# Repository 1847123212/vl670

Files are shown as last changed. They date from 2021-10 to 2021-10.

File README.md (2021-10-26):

VL670/VL671 Development Board - USB 2.0 to 3.0 Transaction Translator
======================================================================

### Revision

This is version v0.02.

The original v0.01 design is obsolete, but it's still
[available here](https://notabug.org/niconiconi/vl670/src/v0.01).

### Introduction

#### The Problem

From a technical standpoint, USB 3.0 SuperSpeed (5 Gbps) is not an
upgrade to the existing USB 2.0 High-Speed (480 Mbps) standard,
instead, USB 3.0 is a completely new system of its own, which
operates independently from USB 2.0. Both the physical and protocol
layer have major differences. Backward compatibility is only maintained
by mandating all USB 3.0 devices to include a separate set of legacy
USB 2.0 controllers, transceivers, and wirings.

Because a USB 3.0 port is really a USB 3.0 and USB 2.0 port slapped
together, it creates some limitations.

* Bandwidth: You may want to simutaneously access multiple USB 2.0
devices, such as many USB flash drives, video cameras, or Software
Defined Radios (SDR) over a single USB 3.0 port using a USB hub,
since it has 5 Gbps bandwidth. However, you cannot do this - the total
bandwidth of all USB 2.0 devices is still limited to 480 Mbps, just
like a regular USB 2.0 port.

* Signal Extension and Isolation: Counter-intuitively, it's easier to
transmit USB 3.0 signals (not USB 2.0 High-Speed) over long distances,
or to galvanically isolate them. Its physical layer is actually simpler
than USB 2.0 - it uses two pairs of unidirectional, 8b/10b encoded,
differential signals. This type of signal is commonly found in almost
all high-speed digital systems, many standard hardware interfaces and
transceivers exist. On the other hand, USB 2.0 signaling is its own
design, its half-duplex nature further complicates the implementation.
Thus, in some non-standard custom systems, only a USB 3.0 link is
physically available.

For home and office users, both limitations may not be a problem,
but for hardware developers and experimenters who work with custom
systems, this can be problematic.

#### VL670/VL671 Transaction Translator

The VL670/671 is a specialized ASIC developed by VIA Labs, Inc., it's a USB
2.0 to USB 3.0 *transaction translator*, in other words, it translates the
legacy USB 2.0 traffic and transparently upgrades the device to an USB 3.0
SuperSpeed device by emulation, enabling a legacy USB 2.0 device to make use
of USB 3.0. By transparently upgrading a legacy USB 2.0 device to an emulated
USB 3.0 device, both problems are eliminated.

This is not a perfect solution, first, it's technically a violation of the
USB standards, also device compatibility is limited. Nevertheless, it's
still helpful to hardware developers and can solve many practical problems
in hardware Research and Development.

This technology is marketed as "SuperTT" (Super Transaction Translator)
by some OEM vendors.

#### My Project

Due to the specialized nature of the VL670/VL671 ASIC, it's almost unheard of
by most developers.

This project is an effort to create a free and open source hardware design of a
development board for the VL670/VL671 ASIC, to facilitate hardware evaluation and
experiments by other community developers, hopefully to help solving your USB
problems in your custom systems.

This development board is intended solely for hardware or software developers for
use in a research and development setting to facilitate evaluation, experimentation,
or technical analysis. It's not designed for consumer use, and it also should not be
used as a part or subassembly in any finished product.

#### Generations

VL670 is already obsolete. The second generation is VL671. This development board
supports both VL670 and VL671, and the use of VL671 is strongly recommended (though
not without its own problems).

Both chips are highly compatibile, the only modification needed is a single LED
output.  If VL670 is used, solder resistor `R9`, otherwise, solder resistor `R13`.

### Usage

#### LED Status

##### D2

* On: A USB 2.0 device has just connected and its traffic is being translated
to USB 3.0 traffic by VL67x (*VL670 only, not on VL671: or the processor is being
held in reset by the SPI header*).

* Off: A USB 3.0 or 2.0 device is connected and its traffic is passing
through VL670 as-is without any translation.

* Blink: Initial power-on reset, or a USB 2.0 device has just connected (*VL670
only, not on VL671*).

##### D20

* On: The power rail `+5V_SW` for downstream USB-A port is switched on.
Normally, this LED should be always on.

* Off: The power rail `+5V_SW` for downstream USB-A port is switched off.
This indicates the power supply circuit is malfunctional. First, check the
`5V` input, and whether the downstream USB port has a short circuit. Then,
check the USB power switch chip `U4` and pull-down resistor R15.

#### Voltage Level

All I/O are 3.3 V LVCMOS. Applying 5 V TTL level can damage the VL670,
its SPI flash, or both.

Before reading or writing to the Flash via SPI, the 5V power must also be
applied via the USB cable or the pin header. Attempting to program the SPI
Flash with an external programming without applying 5V power can damage
components.

#### SPI header

An SPI pin header is located at the top right of the board. By default, it's
connected directly to both the VL670 controller and its SPI Flash, allowing
one to probe the SPI bus while the controller is running. In this default mode,
applying voltages to the SPI header is prohibited, otherwise damage may occur.

To read or write the Flash via SPI, the `/EN` (a.k.a `ISP_ENABLE`) pin of the pin
header is grounded (by bridging pin 6 and 7 on the pin header), the processor is
cut off from the SPI bus and held in reset, giving the SPI pin header exclusive
access to the Flash.

For more information, see *Theory of Operation*, section *SPI Debugging and
Programming* and schematics.

#### GPIO header

All GPIO pin header is located at the top left of the board, exposing all
GPIOs of VL67x. Nevertheless, their functionality is unclear and it's
only useful for reverse engineering.

For more information, see *Theory of Operation*, section *Oddities* and
schematics.

### Known Issues

#### Limitations

1. If the USB-C cable is inserted very slowly, USB 3.0 fails, only USB 2.0
is detected, thus forcing the chip to enter USB 2.0 passthrough mode. This
is working by design and it's not a bug, however, it may cause misleading
or confusing behaviors, thus, `R1` and `R2` are removed by default, forcing
VL67x to always work in transaction translator mode.

2. In VL670, USB 3.0 passthrough is not reliable and it's not compatible
with some devices, this is a VL670 limitation. In VL671, USB 3.0 passthrough
is almost completely broken due to firmware limitation, the only compatible
device is a USB 3 Hub, direct attachment of a USB 3 device is not compatible.
Also, because the USB 3 signal path is doubled in passthrough mode, any cable
longer than 50 centimeters may cause enumeration failures. Thus, USB 3.0
passthrough mode should be avoided. If you want to test a combo USB 2/3 device,
I recommend using a pure USB 2.0 hub to completely isolate the USB 3 signals.

    * If you ever need to test USB 3.0 passthrough mode, you should always
    use a short USB-C cable, no longer than 50 centimeters to minimize signal
    loss. The ideal setup for USB 3 passthrough testing is: Host, 50 centimeter
    USB cable, VL671, very short USB cable, USB 3 Hub, device. Failure to follow
    it to cause enumeration and other failures. For USB 2 transaction mode, no
    special precaution is needed.

    * A hybrid VL670 w/ USB hub topology can be used to work around the
    problem, it's briefly in the next section of the document. USB redrivers
    and retimers can also solve the hardware problem (but not the firmware
    bug). Since USB 3 passthrough is already broken enough and adding either
    solution makes the project more complicated, I choose not to do it.

3. The upstream and downstream USB ports have no common-mode chokes for
the signals. Electromagnetic compatibility performance is limited. This
is an intentional decision, since adding them reduces the USB 3 link
budget needed for the already problematic USB 3 passthrough mode.

4. Not all devices are supported by the transaction translator. Sometimes
the incompatibility is a hardware or protocol limitation, other times it
can be a driver problem - many drivers make certain assumptions of the USB
device, which may no longer be true after the device is emulated by VL670
as a SuperSpeed device.

    * USB Attached SCSI (UAS) doesn't work in transaction translator mode.
    But it can be disabled at the device driver of the operating system.

### Images

#### Front and Back of the PCB

Front and Back of the PCB

### Schematics

* [PDF schematics](https://notabug.org/niconiconi/vl670/raw/main/schematics/vl670-schematics.pdf)

* [PDF layout](https://notabug.org/niconiconi/vl670/raw/main/schematics/vl670-layout.pdf)

### BOM

* [Bill of Material](https://notabug.org/niconiconi/vl670/src/main/bom)

### Datasheets

Datasheets for all components on the development board can be found at GitLab.

* [Datasheets Repository](https://gitlab.com/niconicon1/vl670-datasheets)

It contains the following documents.

* [VL670 USB2.0 to USB3.0 Transaction Translator](https://gitlab.com/niconicon1/vl670-datasheets/-/raw/main/DS_VL670_115.pdf)

* [VL671 Low Power USB 2.0 to USB 3.1 Gen1 Transaction Translator](https://gitlab.com/niconicon1/vl670-datasheets/-/raw/main/DS_VL671_080.PDF)

* [HD3SS3220 USB Type-C DRP Port Controller with SuperSpeed 2:1 MUX](https://gitlab.com/niconicon1/vl670-datasheets/-/raw/main/hd3ss3220.pdf)

* [TPS20xxC and TPS20xxC-2 Current Limited, Power-Distribution Switches](https://gitlab.com/niconicon1/vl670-datasheets/-/raw/main/tps2061c.pdf)

* [GD25D10C/05C 3.3V Uniform Sector Standard and Dual Serial Flash](https://gitlab.com/niconicon1/vl670-datasheets/-/raw/main/GD25D05C.pdf)

* [SN74LVC2G66 Dual Bilateral Analog Switch](https://gitlab.com/niconicon1/vl670-datasheets/-/raw/main/sn74lvc2g66.pdf)

* [ESD7104 Low Capacitance ESD Protection Diode for High Speed Data Line](https://gitlab.com/niconicon1/vl670-datasheets/-/raw/main/ESD7104-D.PDF)

* [ESD5B5.0ST1G-N ESD Protection Diode](https://gitlab.com/niconicon1/vl670-datasheets/-/raw/main/ESD5B5.0ST1G-N.pdf)

### Firmware

The firmware for the SPI Flash can be found at GitLab. Both VL670 and VL671
firmware files are included.

* [SPI Flash Firmware](https://gitlab.com/niconicon1/vl670-firmware)

#### Non-Free

Unfortunately, VL670/671 is driven by a microcontroller and requires a
proprietary firmware to operate.

Nevertheless, the firmware is burned into the Flash memory only once after
the device is assembled, and it's fetched by the VL670 ASIC itself, not
uploaded from a user's host computer, nor it executes any code on a user's
host computer or operating system. If we make the firmware read-only and
unmodifiable by pure software, the firmware effectively "vanishes" from the
software domain and becomes a part of the hardware itself, making the hardware
qualifies as free device, just like [how OpenMoko did it](https://lwn.net/Articles/460654/).
Another benefit is improved security, as malicious software is unable to
reprogram the firmware via USB to launch a BadUSB attack.

This is implemented as jumper `JP1`, once the jumper is hardwired on the board,
the Flash is read-only and cannot be modified by software without hardware
modifications.

That being said, this is a somewhat "underhanded" way to bypass the free software
and hardware requirements and this behavior stays exactly at the borderline of
the definition of "free", just moving one more nanometer away makes it non-free.
This is hardly satisfactory! But this is all we have at the current moment.

#### Reverse Engineering

The long term solution is reverse engineering the firmware and writing a free and
open reimplementation. This also enables us to customize the firmware for our
needs, fixing bugs in the firmware, and understanding the behavior of the hardware
better.

But before you start, note that VL670 is already obsolete, its internal
microcontroller also uses an unknown custom architecture, I suspect it's
Xtensa. Its replacement, VL671, uses a different microcontroller (ARM Cortex M3)
and a different firmware.

I suggest leaving the proprietary VL670 firmware as-is since its architecture
is less known and the chip is already obsolete. Instead, work on the VL671
firmware instead.

### Theory of Operation

#### Overview

The heart of the development board is the VL67x controller (`U2`). It has two USB
interfaces on both sides of the chip. The left side is the host side, connnected
to a computer via a USB 3.0 Type-C port (`J2`), the right side is connected to
the device side, via a USB 3.0 Type-A port. All the transaction translation
magic is performed internally by VL67x.

When a USB Type-C cable is plugged into the development board, 5 V power is
applied to the board by the host, the decoupling capacitors on the 5 V rail
starts charging up. Shortly after the 5 V rail settles, the internal power
converters inside the VL67x controller (`U2`) are activated. They are a 3.3 V
LDO, a 1.5 V DC/DC, and a 1.2 V LDO converter, generating the three power rails
for VL670 (on VL671, the 1.5 V & 1.2 V is merged into a single 1.2 V DC/DC
converter), the SPI Flash (`U6`), and the SPI multiplexers (`U3` and `U5`).

When 3.3 V is ready, the VL67x controller (`U2`) leaves the power-on reset
state, timed by the RC circuit `R4` and `C13`, and the processor core inside
VL67x starts operating. VL67x fetches firmware code from the Flash chip GD25D05
(`U6`) via the SPI bus.

Meanwhile, back to USB (`J2`), at the host side, the incoming 3.0 signal lines from
the Type-C cable is demultiplexed by the USB Type-C controller HD3SS3220 (`U1`)
by selecting the correct signal pairs based on the orientation of the Type-C
plug. It occurs almost as soon as the USB cable is plugged in. On the other hand,
the USB 2 signals are shorted together and don't require active demultiplexing.
At this point, VL67x gains access to both USB 3.0 and USB 2.0 signals at the
host side.

Strictly speaking, only the USB 3.0 signals are required since VL67x is a
transaction translator that converts all USB 2.0 traffic to USB 3.0 transparently.
The USB 2.0 differential pair at the host side is only for compatibility -
if one plugs the board into a USB 2.0 port, VL67x disables transaction and enters
USB 2.0 passthrough mode. Because this fallback behavior can confuse the developer
(e.g. for example, if the USB 3.0 cable is defective and the chip always enters
USB 2.0 passthrough mode), optional jumpers, `R1` and `R2`, are installed on the
the USB 2.0 signal lines. USB 2.0 is disconnected completely when the resistors
are removed to simulate a nonstandard, pure USB 3.0 host port without USB 2.0
connection.

Once the firmware in VL67x decides that it's ready, `/DN_PWREN` (pin 37) outputs
a logical `0`, enabling power switch TPS2061C (`U4`) to provide 5 V power (called
`+5V_SW`, for "switched 5 V") to the downstream, device-side USB port (`J4`).
TPS2061C also provides soft-start and short-circuit protection. At this point,
VL67x is ready to accept a USB device.

At the device side, `DN_D-`, `DN_D+`, `DN_USB3RX-`, `DN_USB3RX+`, `DN_USB3TX-`,
`DN_USB3TX+` are connected to a USB Type-A port.

When a USB device is plugged in to the USB-A connector (`J4`)...

* If it's a USB 2.0 device and if USB 3.0 is available at the host side, the
USB 2.0 traffic is translated to USB 3.0 traffic by VL67x. The host should
detect a USB 3.0 SuperSpeed device. The translation is transparent, VL67x
itself is invisible to the host, only the device is.

* If only USB 2.0 is available at the host, VL67x enters USB 2.0 passthrough
mode for all USB 2.0 or USB 3.0 devices, without translation. The host should
detect a USB 2.0 device. This mode is also entered if the USB 3.0 at the host
side has failed. A defective cable is a common cause, but inserting the USB
Type-C cable extremely slowly has the same effect. Removing `R1` and `R2` to
disable USB 2.0 at the host completely can avoid this confusing situation.

* If both the host and device support USB 3.0, VL67x enters passthrough mode
without translation.

#### USB Type-C and HD3SS3220

For developer's convenience, the USB host side uses a USB 3.0 Type-C connector
instead of a bulky and uncommon USB 3.0 Type-B or Micro-USB connector.

A USB 3.0 Type-C connector is reversible, thus it has two possible connections:
either `D1+`, `D1-`, `TX1+`, `TX1-`, `RX1+`, `RX1-` are connected, or `D2+`, `D2-`,
`TX2+`, `TX2-`, `RX2+`, `RX2-` are connected. USB 2.0 operates at a slower
frequency, thus `D1+/-` and `D2+/-` pairs are simply shorted together, allowing
a connection regardless of the plug orientation.

On the other hand, this is unacceptable for USB 3.0 - the extra length of an
open-ended wiring creates a quarter-wave stub, which is detrimental to signal
integrity. Instead of passively connecting them together, an active electronic
switch, known as an demultiplexer, should be used to select one out of two
pairs.

The solution is HD3SS3220 (`U1`), it's a USB-C controller with built-in
switches. It automatically selects the correct differential pair, either `TX1+`,
`TX1-`, `RX1+`, `RX1-` or `TX2+`, `TX2-`, `RX2+`, `RX2-`, based on the
orientation of the Type-C plug as soon as a Type-C cable is plugged in.
The demultiplexed signal is simply called `TX+`, `TX-`, `RX+`, `RX-`,
just like the signal coming out from a traditional USB 3.0 Type-B connector.

##### DC Biasing

The `TX-` and `TX+` pins on the HD3SS3220 can only tolerate a common-mode
DC voltage below 2 V. But VL67x's common-mode DC voltage at SSTX is 2.2 V. Two
extra capacitors, C5 and C6 are needed in this particular design to prevent
VL67x's DC bias from reaching HD3SS3220.

Simultaneously, HD3SS3220 won't work without a DC bias at the `TX-` and `TX+`
pins. Thus, R16 and R17 are needed to reestablish a DC operating point. 0 V
is acceptable, thus both are pulled down to GND. The resistors are unnecessary
without HD3SS3220.

#### SPI Debugging and Programming

An SPI pin header (`J3`) is provided at the top right of the board. The header is
directly connected to the signal lines between the VL67x controller and the
GD25D05 (`U6`) SPI Flash, allowing one to attach a logic analyzer to monitor the
bus while the controller is running.

To allow a developer to read or write the Flash via SPI directly without a
potentially destructive bus contention, VL67x's SPI bus is gated by two
74LVC2G66 CMOS analog switches (`U3` and `U5`). When the `/EN` (a.k.a `ISP_ENABLE`)
pin of the pin header is grounded (by bridging pin 6 and 7 on the pin header),
the processor is cut off from the SPI bus, giving the SPI pin header exclusive
access to the Flash. The `/EN` signal is also directly connected to the `/RESET`
signal of VL67x to halt the processor.

#### External Power

A power pin header (`J5`) is provided. However, it should never be used to power
the development board when the USB Type-C port is plugged in, otherwise a short
circuit may occur. If debugging the board with external power is desirable, cut
the trace at PCB jumper `JP2` with a knife.

The jumper is located at the back side of the board. There are two jumpers, so
make sure you're cutting `JP2`. Use a multimeter to confirm the connection is
truly broken.

Once `JP2` is cut, the USB Type-C port no longer provides power to the
development board. Signals and ground connections remain.

#### Oddities

Due to OEM firmware differences, some pins do different things than what
they were intended to do. These differences were obtained via hardware
reverse engineering.

##### GPIO

* `GPIO1_3 / DN_PWREN` is meant to be an `/ENABLE` signal to the downstream
USB port, but it seems to be high-impedance and unused by the firmware. Thus,
the USB power switch U2 is optional and can be removed. Its only purpose is
short circuit protection.

##### USB 3 Passthrough

The reverse-engineered hardware uses a slightly different topology -
VL67x is attached to an upstream USB 3.0 hub as a subdevice, and only
USB 2.0 signals are wired to the downstream VL670, the USB 3.0 signals
are directly wired to the upstream hub. This can be understood as an
attempt to improve compatibility. In my tests, I found the USB 3.0
passthrough offered by VL670 is not always reliable and some devices
cannot be used, and on VL671 it's essentially broken due to firmware
limitations. Furthur, because the USB 3 signal path is doubled in
passthrough mode, it completely breaks the USB link budget, any cable
longer than 50 centimeters may cause enumeration failures.

Thus, passthrough mode should be avoided. Wiring the USB 3.0 signal
directly to the host via a USB 3.0 hub is beneficial.

For simplicity, this is not implemented on this development board. But
it's necessary for a finished product.

##### VL670 GPIO

* `GPIO1_2 / GPIO_TP3` is officially unused, but the OEM firmware uses it as
an input for deciding whether to enable VL670. On this development board, this
pin is pulled down by a resistor, otherwise the USB connection would reset
randomly.

On the reverse-engineered hardware, the downstream hub `/ENABLE` seems to
be Wired-Or together with `DN_PWREN` output, the `ENABLE` pin output from
the upstream USB Hub (to allow both chips to make a `ENABLE` decision?),
and the input `GPIO1_2`. It appears to be a workaround to allow the use
of aforementioned hybrid topology.

* `GPIO1_0 / GPIO_TP1` is officially unused, but the OEM hardware connects it
to the USB hub's (not VL670's own) private SPI bus, between the hub and its SPI
firmware Flash, monitoring the `MISO` signal. On this development board, this
pin is pulled down by a resistor. Although it seems to work without one, but
leaving the input in a known state is still desirable as we don't really
understand its purpose.

Again, a odd design, and I suspect the firmware is using it as an interrupt
signal to detect whether the USB hub is active for logic sequencing or
synchronization in this hybrid VL670 w/ hub topology.

* `GPIO3_0 / STATUS` is meant to be the LED indicator output, but the
firmware uses `GPIO1_1/GPIO_TP2` instead.

* `UART_RX` and `UART_TX` - no traffic observed. More hacking required.

#### Power Distribution Network

##### Overview

The Power Distribution Network is decoupled using the standard method of
"one capacitor per pin, all capacitors have the same value."

The 1.5 V rail and 1.2 V rail are decoupled using 1 uF capacitors, all
0603-sized, nothing unusual (but do note C44 is the output capacitor of
the DC/DC converter).

The 3.3 V rail uses multiple (20+) 470 nF capacitors and deserves more
attention: C31-C35 are meant for power supply decoupling, and are 0603-sized.
C71-C82 however, serve double duties, they are placed near vias to provide a
continuous AC return path for signals travelling between layers ("plane
stitching"), thus are 0402-sized to fit in the tight space near vias. Due to
the higher number of capacitors for plane stitching, smaller 470 nF capacitors
are used to keep the total capacitance per rail under 10 uF to prevent inrush
current.

##### USB Inrush Current

The 5 V rail requires special care, it's directly attached to the USB power
input, thus will produce a huge inrush current, which should stay within the
USB spec limits. Basically, the rules of the USB spec is:

1. Inrush current less than 100 mA is always acceptable, it's only considered
as an inrush event when 100 mA is exceeded.

2. If an inrush event occurs, the maximal *charge* transfered, calculating by
area under the current curve, should be less than 50 uC. For 5 V, it means the
equivalent capacitance should be less than 10 uF. Only *charge* is limited, not
inrush current itself, because the goal is to avoid draining the output
capacitance at the upstream by too much, the absolute current is irrelevant (of
course, unless it's low enough to apply rule No.1).

3. If two inrush events are separated by 100+ us, they are considered as two
separate events. Only the "biggest" inrush event is considered, all other
events are ignored. Thus, it's possible to get more capacitance allowance
by delayed startup.

Measurements showed that the only significant inrush current of this development
board is caused by capacitors at 5 V rail, other power rails produces almost no
inrush current, presumably, the LDO and DC/DC's startup is "soft" enough.
Moreover, the current capacitance on 5 V rail is rather conservative, only 5 uF,
due to the delayed (100 us+) startup of `+5V_SW` rail, the total capacitance
allowed on the +5 V rail is effectively doubled, up to 20 uF (effectively 10 uF
due to ceramic capacitance loss under DC bias, giving us some extra headroom).

##### Ferrite Resonance and Damping

A ferrite choke, FB1, is used in series of the 5 V input at the USB port to
filter high-frequency noise. However, its series inductance, when combined
with parallel capacitance, forms a parallel LC circuit on the 5V rail. This
creates a huge impedance spike at the resonance frequency. If this frequency
is excited by noise, it create a huge noise voltage. To reduce its impact,
two small 0.5-ohm resistors are connected in series with the ceramic capacitors,
C19 and C20.

##### Capacitor Value Selection

Finally, it should be noted that a 0.1 uF capacitor is traditionally seen as
a "high-frequency capacitor" and is the prefered choice for power decoupling,
and is often blindly combined with 1 uF capacitors to "cover both high and
low frequencies." However, many recent books by domain experts have pointed out
that this practice is counterproductive. First, blindly mixing capacitor
values can create anti-resonance impedance peaks and actually make the
decoupling worse at some frequencies. Second, considering that this rule of
thumb originated from the through-hole era, meanwhile the parasitic inductance
of modern SMD ceramic capacitors is so low, they all have fairly good
high-frequency performance regardless of their values, their effectiveness is
mainly limited by package size and PCB inductance. Thus, the modern, updated
guideline is to use the same capacitance everythere. That being said, there
are still important uses and benefits for mixing different capacitance, but
only if careful calculation and simulation is performed to predict and control
the anti-resonance peaks - which is overkill for this board.

For the argument against multiple capacitor values, see *Electromagnetic
Compatibility Engineering* by Henry Ott, Chapter 11 *Digital Circuit Power
Distribution*, Section 11.4.1 *Multiple Decoupling Capacitors*. And for the
argument for multiple capacitor values, but with careful design and simulation,
see *Principles of Power Integrity for PDN Design* by Larry D. Smith and Eric
Bogatin, Chapter 8 *The PDN Ecology*, Section 8.17 *Using Three Different
Values of MLCC Capacitors on the Board*.

P.S: Smith & Bogatin's conclusions are terrifying, I'll just pretend that I
don't know that...

#### PCB Stack-up

This is a 4-layer PCB, using the Signal-Ground-Power-Signal stack-up
with impedance controlled traces, and fabricated by JLCPCB's JLC2313
stack-up. The dielectric constant of the board is 4.05, the distance
between the signal and its reference plane is 0.1 mm.

JLC2313 is selected for its closer distance between the signal and its
reference plane in comparison to JLC7628, which allows thinner traces
and reduced crosstalk.

### License

Copyright (C) 2021 Tom Li (niconiconi)
"No Rights Reserved"

This is a free hardware design: to the extent possible under law, the designer
has waived all copyright and related or neighboring rights, you can reuse,
modify, redistribute this design, as freely as possible in any form whatsoever
and for any purposes, including commercial purposes, under the terms of the
*CC0 1.0 Universal License*.

This hardware design is offered as-is and the designer makes no representations
or warranties of any kind concerning the design, express, implied, statutory or
otherwise, including without limitation warranties of title, merchantability,
fitness for a particular purpose, non infringement, or the absence of latent
or other defects, accuracy, or the present or absence of errors, whether or
not discoverable, all to the greatest extent permissible under applicable law.

See the *CC0 1.0 Universal License* for more details.

You should have received a copy of the *CC0 1.0 Universal License* along with
this hardware design. If not, see https://creativecommons.org/publicdomain/zero/1.0/legalcode

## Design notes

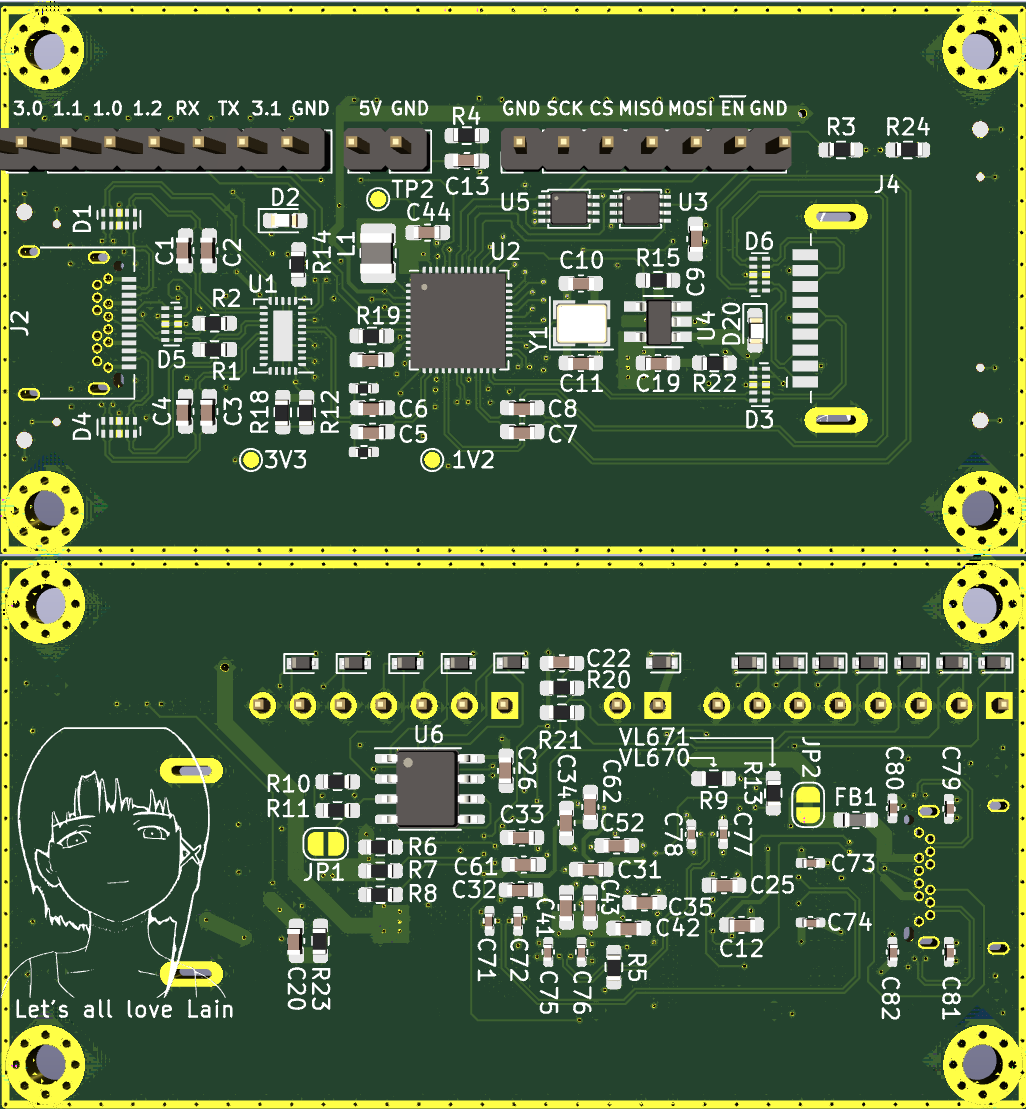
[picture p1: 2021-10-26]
photos/pcb_render.png

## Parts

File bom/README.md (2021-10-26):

VL670 Development Board - BOM
===============================

Don't trust the price data too much. 

### PCB

| Component |  Quantity  | Price  | Total Low Qty. Price
| --- | --- | --- | --- |
| JLCPCB, 4-layer, JLC2313 stack-up, ENIG | 1 | 4.72  | 23.58 |
| | | =  4.72  | = 23.58 |

### Assembly
| Component |  Quantity  | Price  | Total Low Qty. Price
| --- | --- | --- | --- |
| JLCPCB, stencil, etch-polishing | 1 | 0.000  | 14.48 |
| | | = 0.000  | = 14.48 |

### Capacitors

| Component |  Quantity | Price  | Total Price | Total Low Qty. Price 
| --- | --- | --- | ---| --- |
| 0603 X7R 220nF | 8 | 0.0115 | 0.092 | 0.575 |
| 0603 NP0  18pF | 2 | 0.0051 | 0.0102 | 0.255 |
| 0603 X7R 1uF | 10 | 0.0254 | 0.3048 | 0.508 |
| 0603 X7R  10uF | 2 | TBD  | TBD | TBD |
| 0603 X7R 470nF | 9 | 0.0198 | 0.1782 | 0.99 |
| 0402 X7R 470nF | 12 | 0.0124 | 0.1488 | 0.62 |
| | | |  = 0.7344 | = 3.618 |

### Resistors

| Component |  Quantity | Price  | Total Price | Total Low Qty. Price
| --- | --- | --- | ---| --- |
| 0603 5%  0.5  | 2 |  TBD | TBD | TBD |
| 0603 5% 10K | 7 | 0.0046 | 0.0322  | 0.23 |
| 0603 5%  470  | 1 | 0.0013 | 0.0013  | 0.13 |
| 0603 1% 11.3K | 1 | 0.0014 | 0.0014  | 0.14 |
| 0603 1%  1.8M | 2 | 0.0016 | 0.0032  | 0.16 |
| 0603 5%  200K | 1 | 0.0459 | 0.0459  | 0.46 |
| 0603 -% 0  | 6 | 0.0015 | 0.0090  | 0.15 |
| 0402 5%  100K | 2 | 0.0117 | 0.0234  | 0.59 |
| | | | = 0.4062  | = 1.86 |

### Inductors & Ferrites

| Component | Value |  Vendor |  Quantity  | Price  | Total Price | Total Low Qty. Price
| --- | ---  | --- | --- | --- | --- | --- |
| SPH252012H4R7MT | 0603 4.7uF |  Sunlord | 1 |  0.1178  | 0.1178 | 1.18 |
| BLM18KG221SN1D  | 0606 220R/2.2A |  Murata | 1 | TBD | TBD | TBD |
| | | | | | = 0.1178 | = 1.18 |

### ESD Suppression Diodes

| Component | Vendor |  Quantity |  Price  | Total Price | Total Low Qty. Price
| --- | ---  | --- | --- | --- | --- |
| UDFN  ESD7104 | OnSemi | 5 |  0.0987 | 0.4935 | 1.2326 (shortage!) |
| SOD-523 ESD5B5.0ST1G-N | Born Semiconductor | 12 |  0.0368 | 0.4416 | 0.74 |
| | | | | = 0.9351 | = 1.9726 |

### Connectors

|  Component | Value |  Vendor |  Quantity  |  Price  | Total Price | Total Low Qty. Price
| --- | --- | --- | --- | --- | --- | --- |
|  USB 3 Type-C  | U262-241N-4BV60 | XKB | 1 |  0.5266 | 0.5266 | 0.53 |
|  USB 3 Type-A  | U231-091N-4BLRA00-S-1 | XKB | 1 |  0.1722 | 0.1722 | 0.1722 |
| 2.54mm header  | 01x02, 01x07 | - | 1 |  0.0244 | 0.0244 | 0.0244 |
| | | | | |  = 0.7232 | = 0.7266 |

### Misc

| Component | Value |  Vendor |  Quantity  |  Price  | Total Price | Total Low Qty. Price
| --- | --- | --- | --- | --- | --- | --- |
| 0603 Blue  LED  | Blue | - | 1 | 0.0294  | 0.0294 | 0.59 |
| 3225 25MHZ XTAL |  25 MHz, Cl=10pF  | - | 1 | 0.0098  | 0.0098 | 0.49 |
| | | | | |  = 0.0392 | = 1.08 |

### ICs

| Component | Vendor |  Quantity | Price  | Total Price | Total Low Qty. Price
| --- | ---  | --- | --- | --- | --- |
|  QFN-48 VL67X |  VIA Labs | 1 |  3.0817  | 3.0817 | 4.6225 |
| WQFN-30 HD3SS3220 | TI | 1 |  1.7907  | 1.7907 | 3.4515 (shortage!) |
| VSSOP-8 74LVC2G66 |  Nexperia, TI | 2 |  0.2337  | 0.4674 | 0.4674 |
|  SOIC-8 GD25D05 |  GigaDevice | 1 |  0.4097  | 0.4097 | 2.00 |
| SOT-23-5 TPS2061C-PXLI | TI | 1 |  0.7682  | 0.7682 | 0.7682 |
| | | | | = 6.5177 | = 11.3096 |

### Total:

| Component |  Total Price  | Total Low Qty. Price
| --- | --- | --- |
| PCB | 4.72 | 23.58 |
| Capacitors | 0.7344 | 3.618 |
| Resistors | 0.4062 | 1.86 |
| Inductors | 0.1178 | 1.18 |
| ESD Suppression Diodes | 0.9351 | 1.9726 |
| Connectors | 0.7232 | 0.7266 |
| Misc | 0.0392 | 1.08 |
| ICs | 6.5177 | 11.3096 |
| |  = 14.196 | = 46.50 |
| + assembly | | = 60.99 |

Note: the "Total Low Qty. Price" is only for my personal reference, the method
is not rigorous and seems to overestimates the sample board cost. The "true"
cost is probably $20.

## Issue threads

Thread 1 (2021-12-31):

Supertt adapter v2

docop, 2021-12-31:
Hi So this is a very great project. I spend lot of time to find out those unit and overall only 1 place in china did do it. But it do heat up to the point to burn. quite special.  Is yours, based on the ref design get any heat issues ?
 And did you have working prototype of your v2 version ? or made multiple..
thanks in advance

docop, 2023-03-16:
Also, is the hid usb1 do transfert too ?

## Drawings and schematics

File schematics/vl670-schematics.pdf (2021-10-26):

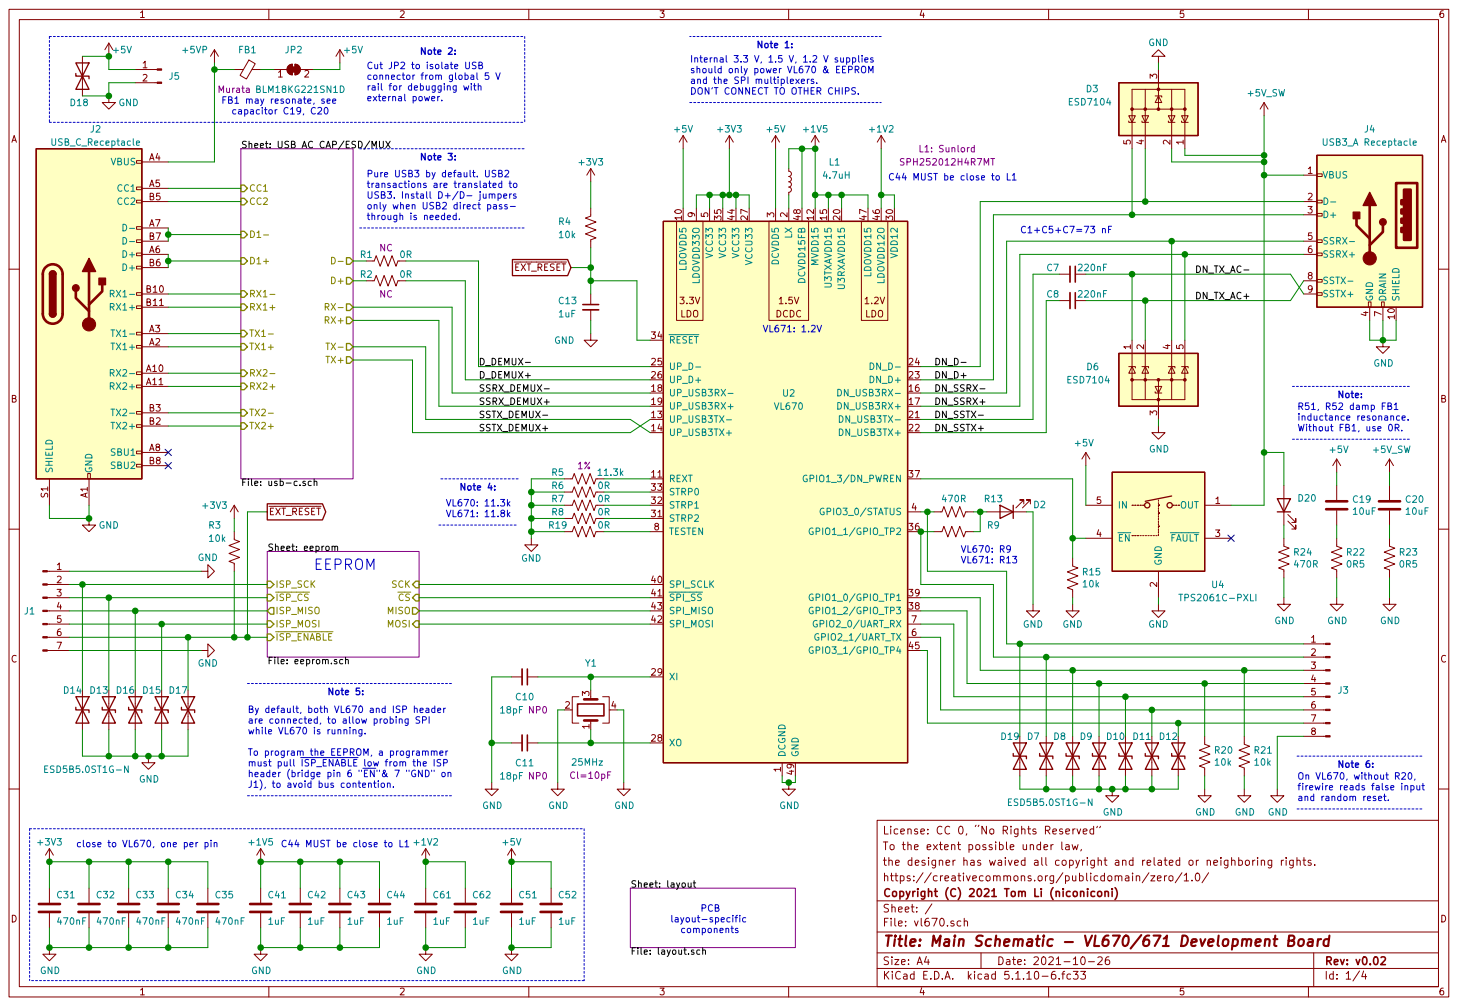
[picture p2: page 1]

and the SPI multiplexers. DON'T CONNECT TO OTHER CHIPS. VL670: 11.3k VL671: 11.8k Cut JP2 to isolate USB
connector from global 5 V
rail for debugging with
external power.

Internal 3.3 V, 1.5 V, 1.2 V supplies
should only power VL670 & EEPROM

Sheet: USB AC CAP/ESD/MUX

inductance resonance. Without FB1, use 0R. Note 3: Pure USB3 by default. USB2

SPH252012H4R7MT
C44 MUST be close to L1

transactions are translated to USB3. Install D+/D- jumpers

only when USB2 direct pass-

By default, both VL670 and ISP header
are connected, to allow probing SPI
while VL670 is running.

To program the EEPROM, a programmer
must pull ISP_ENABLE low from the ISP
header (bridge pin 6 "EN"& 7 "GND" on

firewire reads false input and random reset. Note 6:
On VL670, without R20,

License: CC 0, No Rights Reserved
To the extent possible under law,
the designer has waived all copyright and related or neighboring rights.
https://creativecommons.org/publicdomain/zero/1.0/
File: vl670.sch Sheet: / Copyright (C) 2021 Tom Li (niconiconi)

Id: 1/4 Title: Main Schematic - VL670/671 Development Board

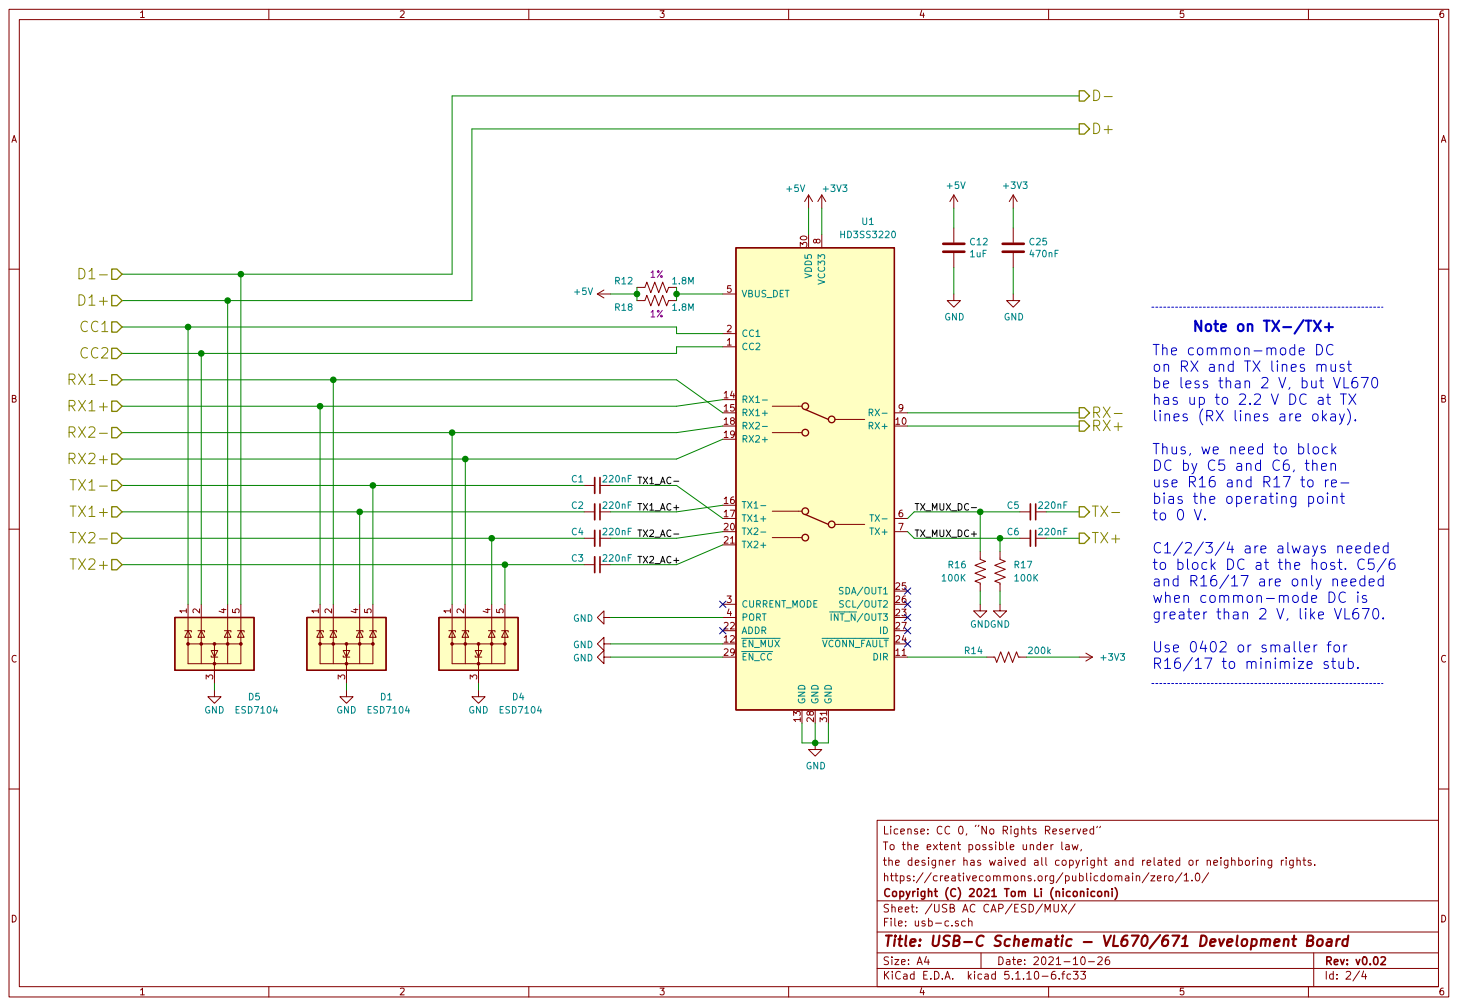
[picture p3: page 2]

The common-mode DC
on RX and TX lines must
be less than 2 V, but VL670
has up to 2.2 V DC at TX
lines (RX lines are okay).
Thus, we need to block
DC by C5 and C6, then
use R16 and R17 to re-
bias the operating point
C1/2/3/4 are always needed
to block DC at the host. C5/6
and R16/17 are only needed
when common-mode DC is
greater than 2 V, like VL670.
Use 0402 or smaller for
R16/17 to minimize stub.

License: CC 0, No Rights Reserved GND

To the extent possible under law,
the designer has waived all copyright and related or neighboring rights.
https://creativecommons.org/publicdomain/zero/1.0/
File: usb-c.sch Sheet: /USB AC CAP/ESD/MUX/ Copyright (C) 2021 Tom Li (niconiconi)

Id: 2/4 Title: USB-C Schematic - VL670/671 Development Board

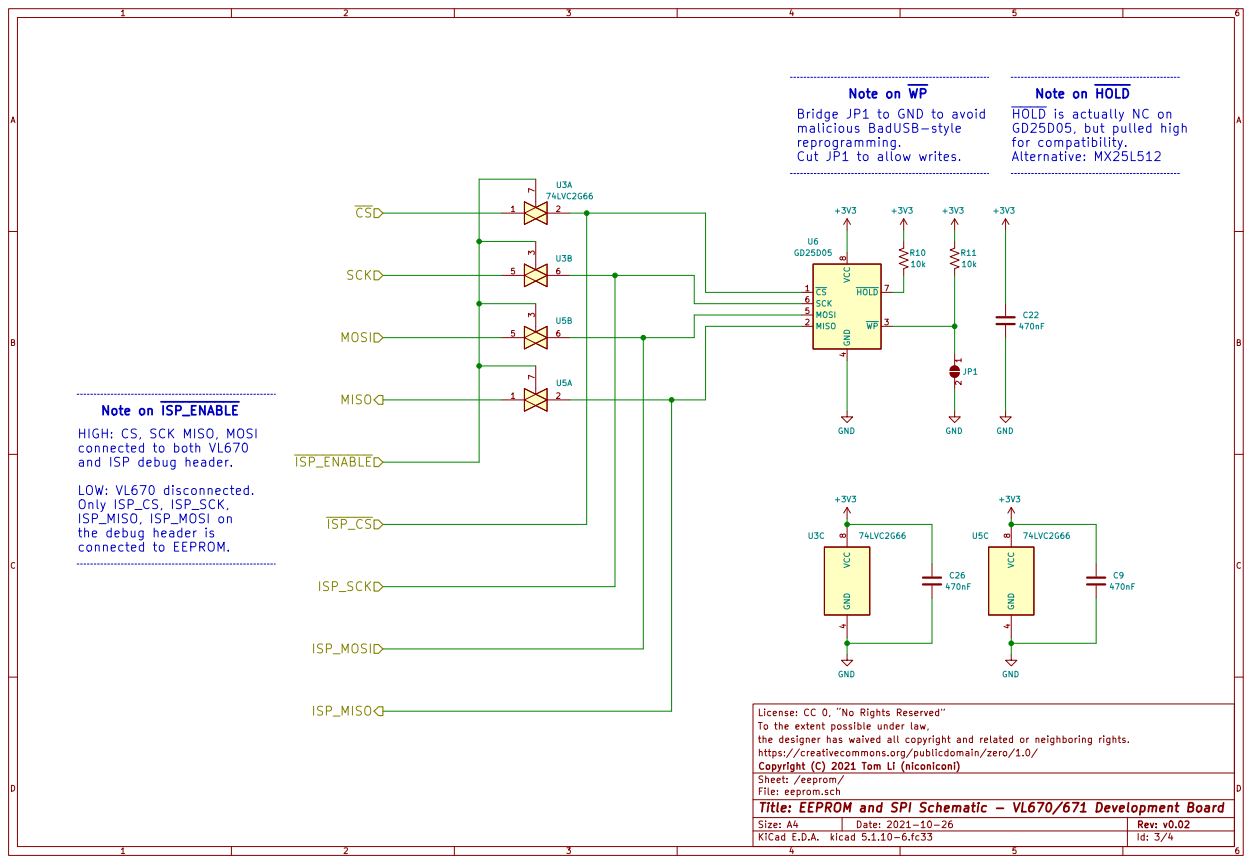
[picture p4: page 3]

Bridge JP1 to GND to avoid
malicious BadUSB-style
reprogramming.
Cut JP1 to allow writes.

HOLD is actually NC on
GD25D05, but pulled high
for compatibility.
Alternative: MX25L512

4 MOSI 5 SCK 6 HOLD 7 VCC

Note on ISP_ENABLE
HIGH: CS, SCK MISO, MOSI
connected to both VL670
and ISP debug header.
LOW: VL670 disconnected.
Only ISP_CS, ISP_SCK,
ISP_MISO, ISP_MOSI on
the debug header is
connected to EEPROM.

License: CC 0, No Rights Reserved GND

To the extent possible under law,
the designer has waived all copyright and related or neighboring rights.
https://creativecommons.org/publicdomain/zero/1.0/
Copyright (C) 2021 Tom Li (niconiconi)
Sheet: /eeprom/
File: eeprom.sch
Id: 3/4 Title: EEPROM and SPI Schematic - VL670/671 Development Board

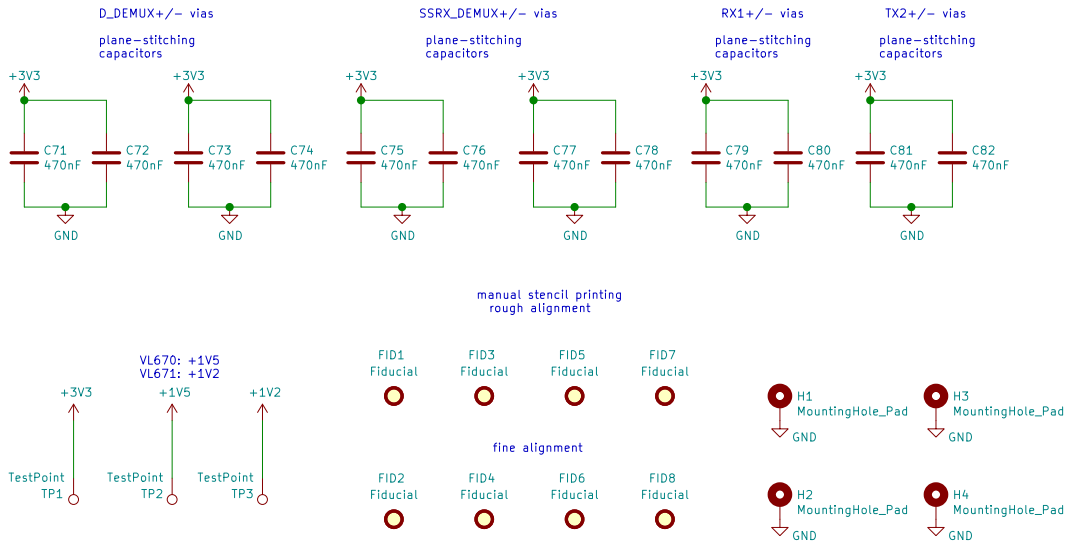
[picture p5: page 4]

fine alignment D_DEMUX+/- vias plane-stitching

License: CC 0, No Rights Reserved
To the extent possible under law,
the designer has waived all copyright and related or neighboring rights.
https://creativecommons.org/publicdomain/zero/1.0/
Copyright (C) 2021 Tom Li (niconiconi)
Sheet: /layout/
File: layout.sch
Id: 4/4 Title: PCB-specific Schematic - VL670/671 Development Board

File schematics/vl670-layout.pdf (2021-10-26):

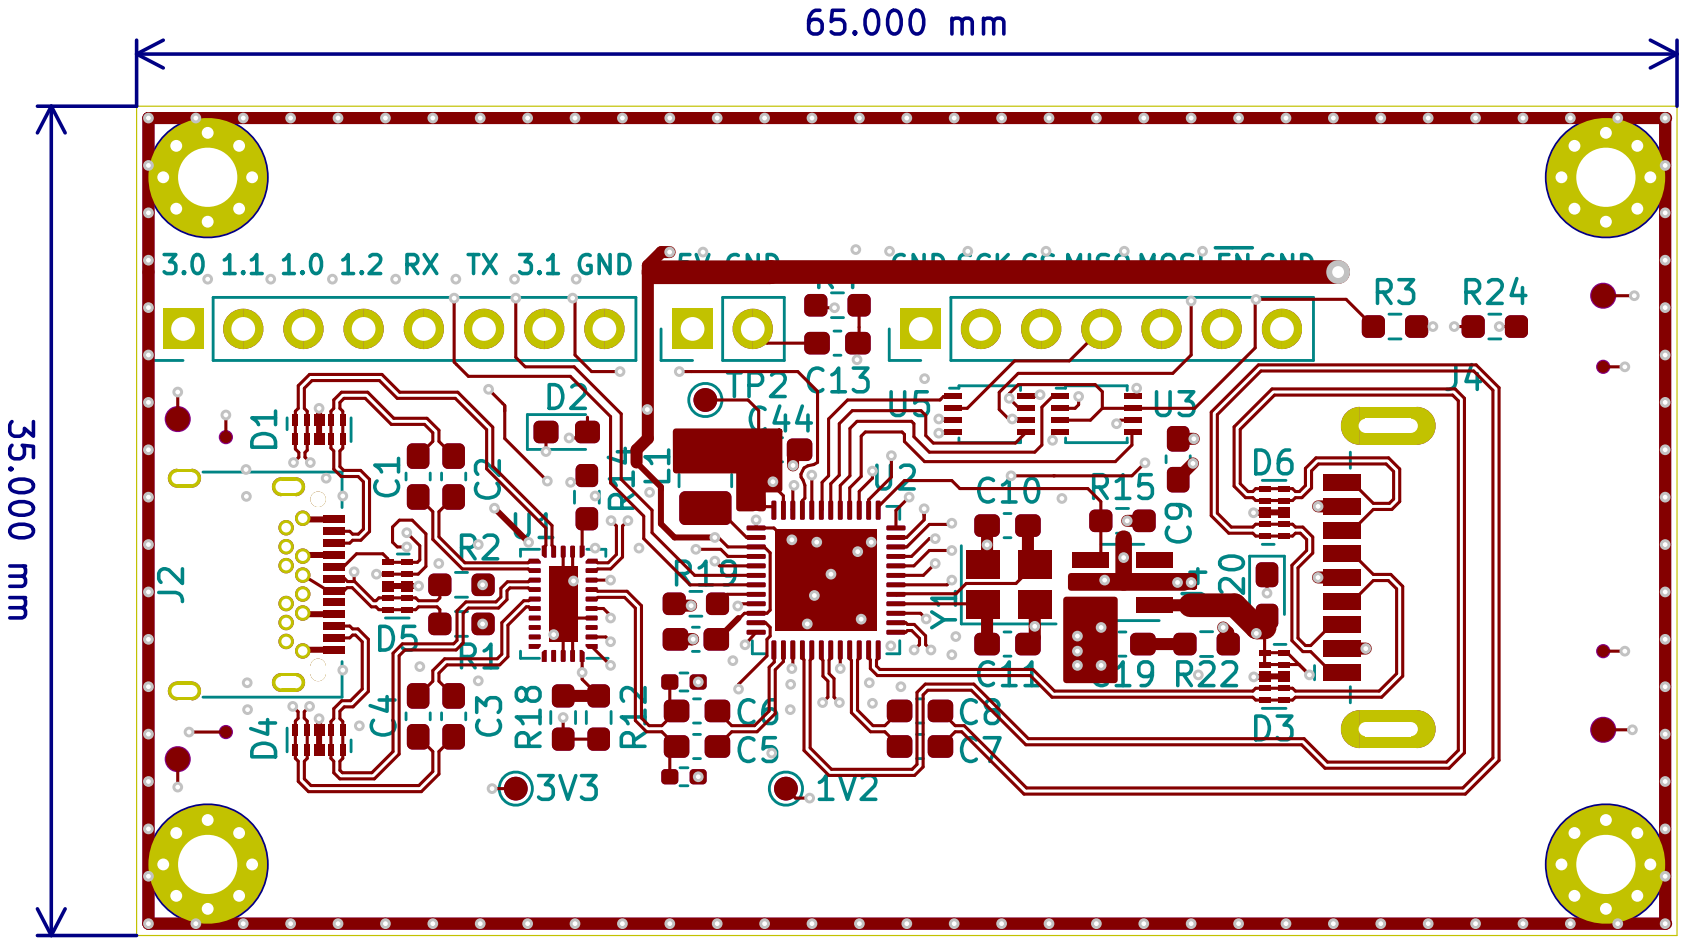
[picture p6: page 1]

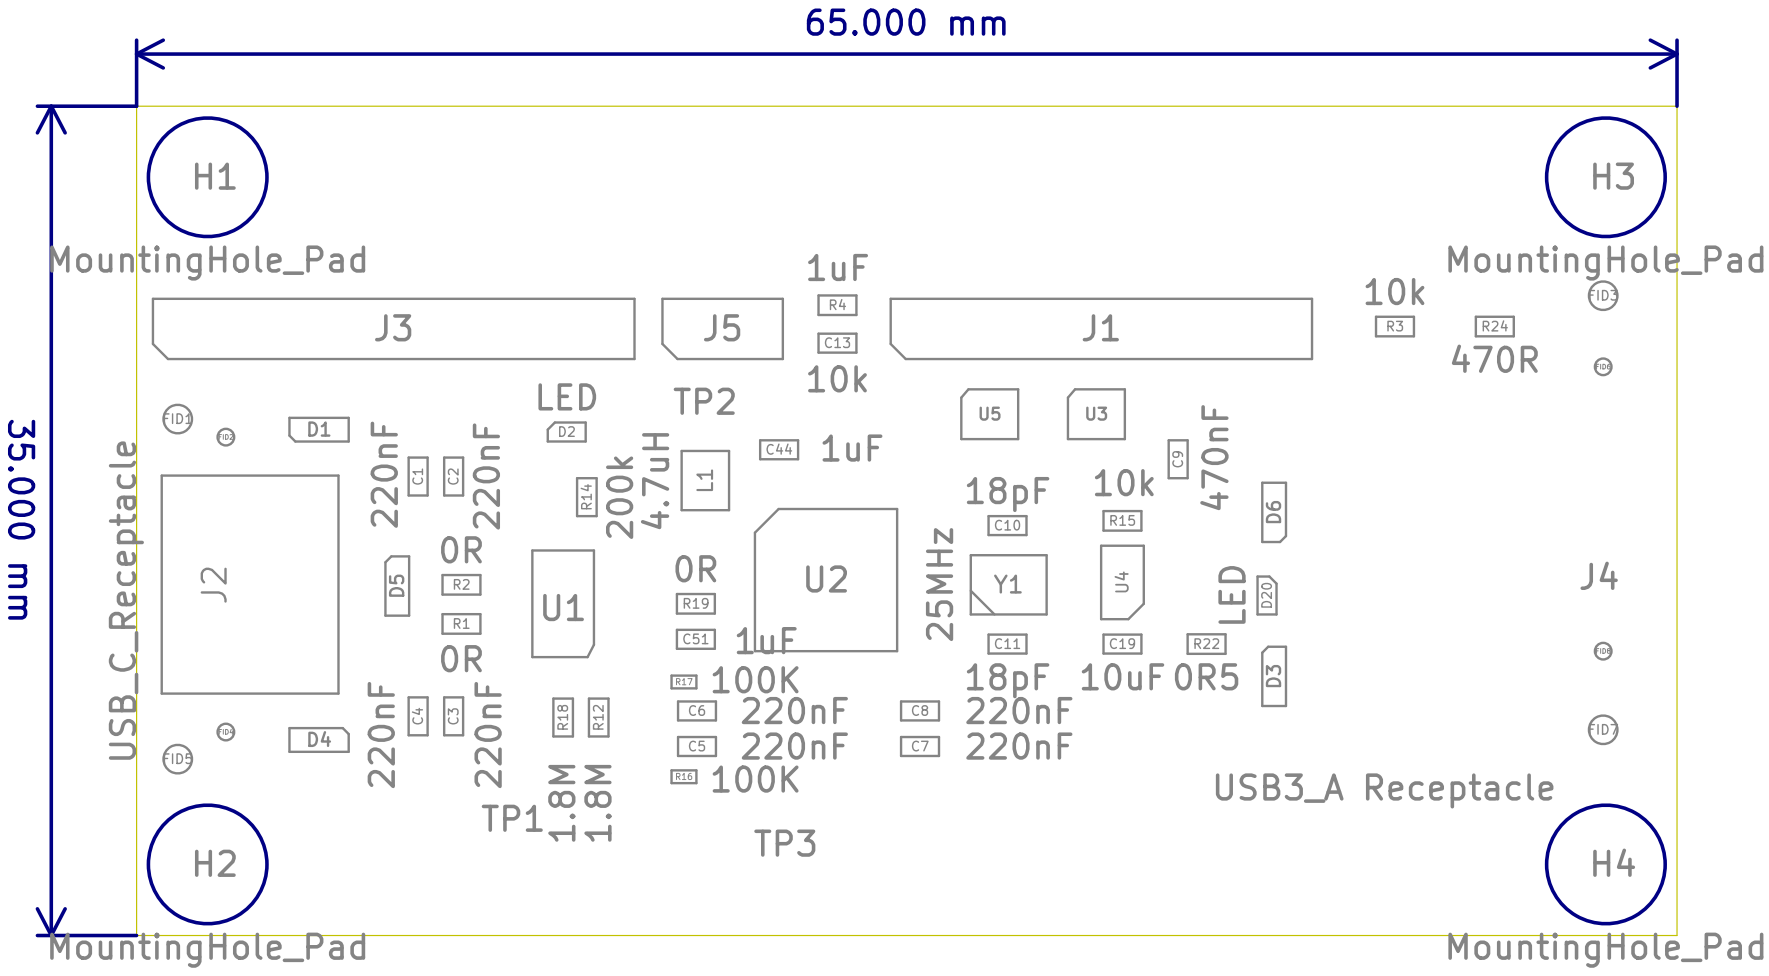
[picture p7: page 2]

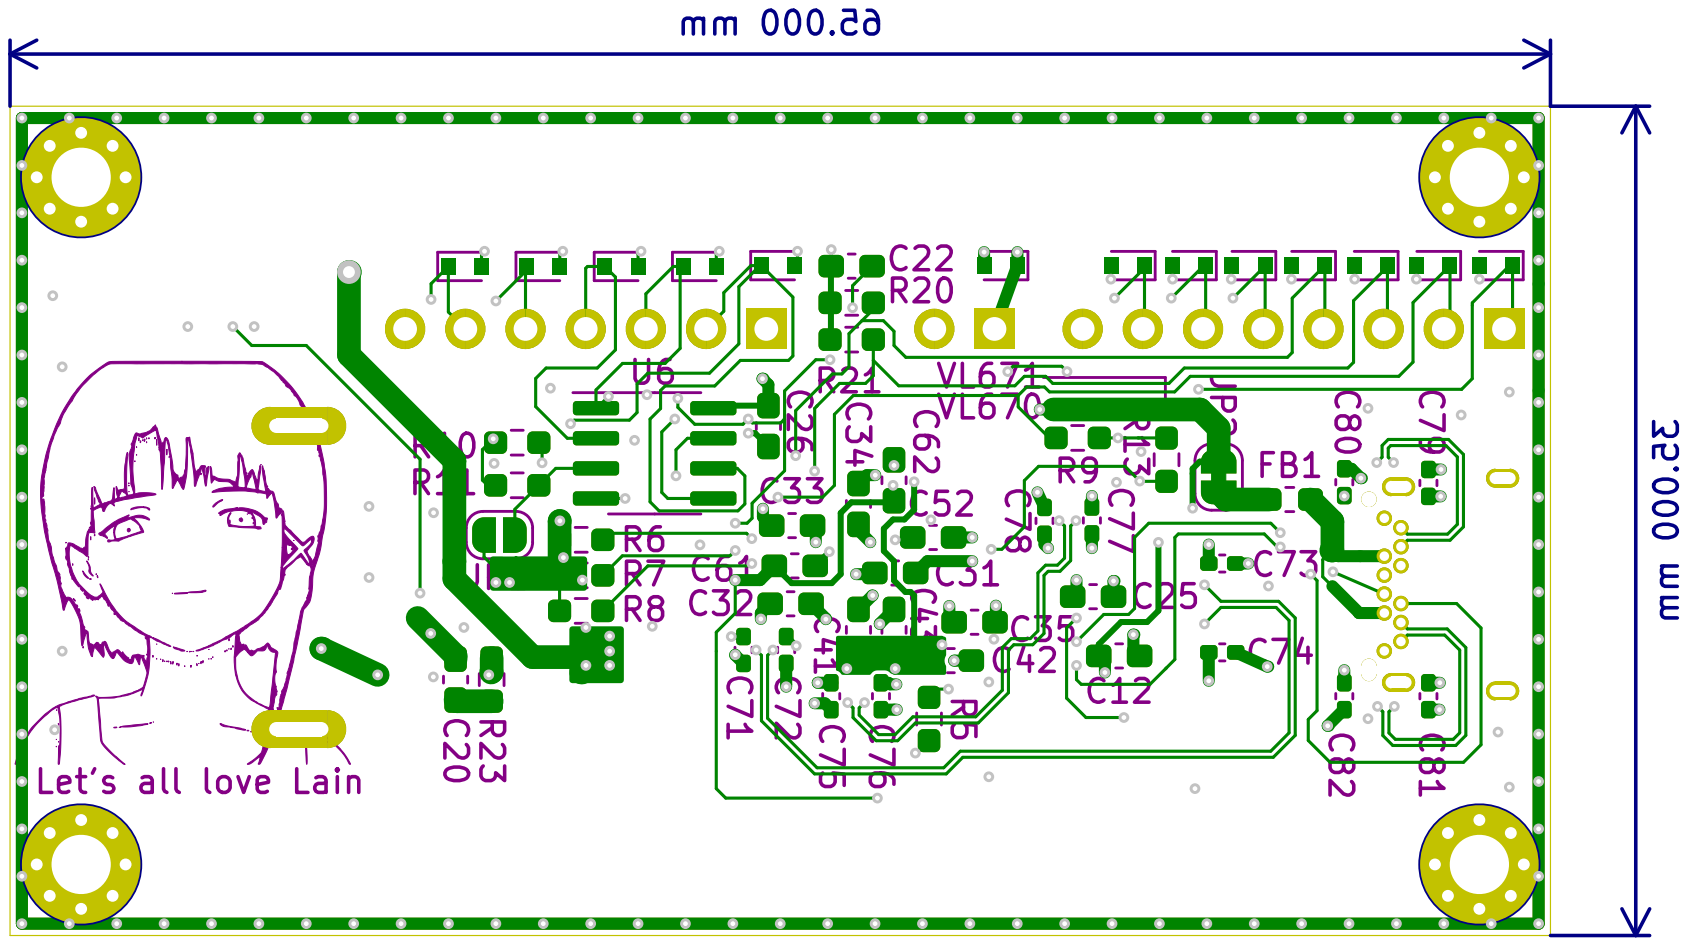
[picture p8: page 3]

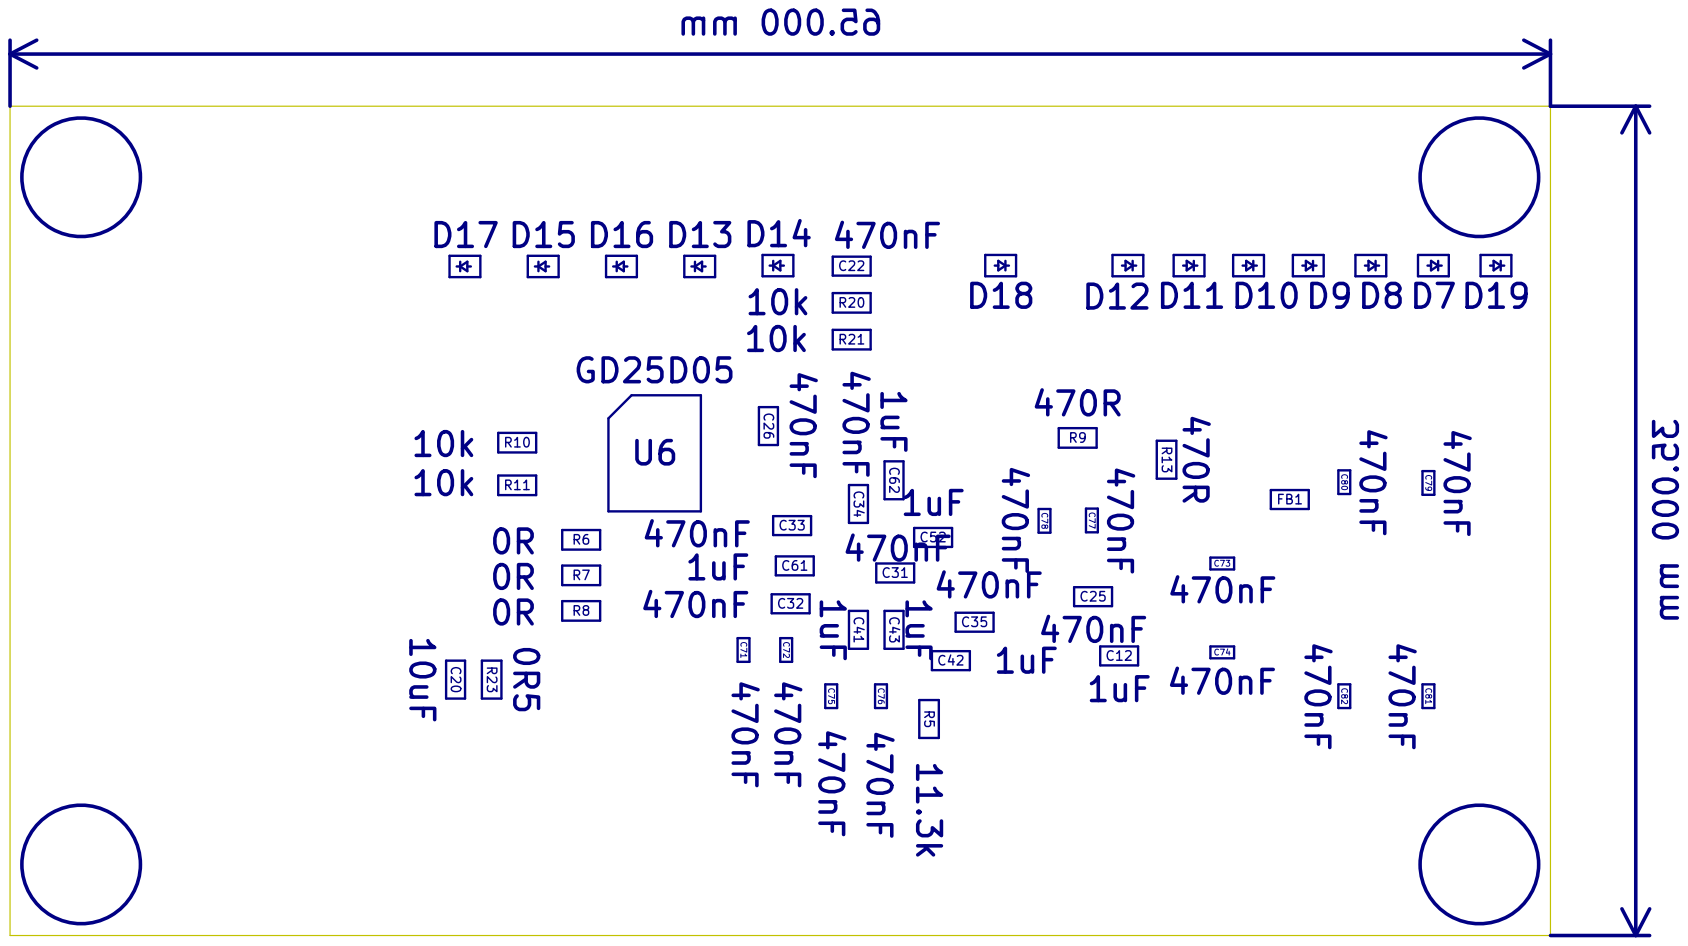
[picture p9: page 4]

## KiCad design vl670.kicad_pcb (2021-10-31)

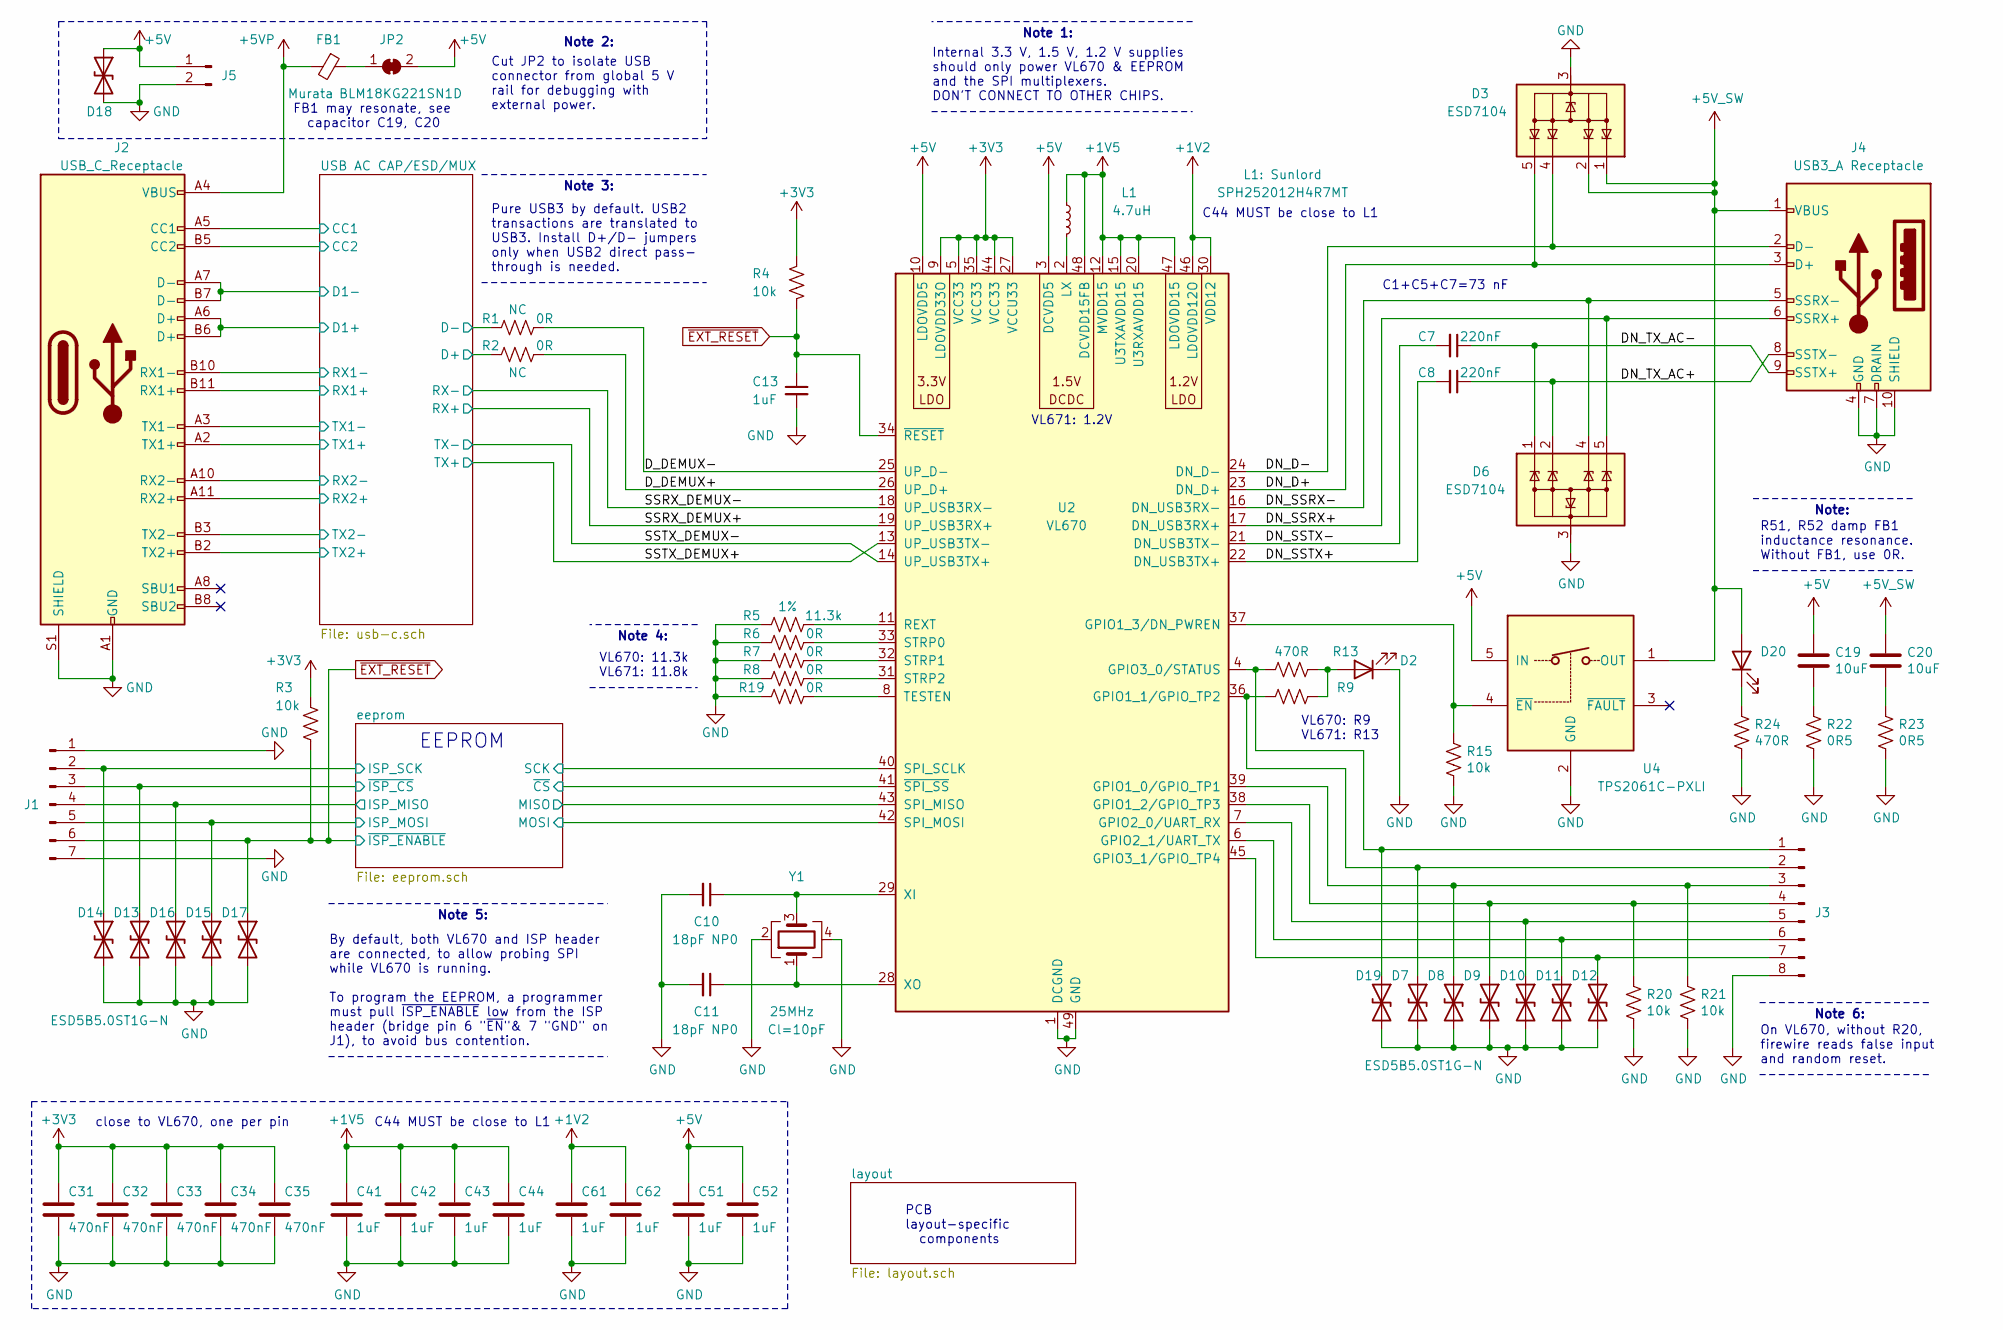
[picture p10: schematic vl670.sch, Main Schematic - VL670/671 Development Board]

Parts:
C7, C8: 220nF; C_0603_1608Metric_Pad1.08x0.95mm_HandSolder
C10, C11: 18pF; C_0603_1608Metric_Pad1.08x0.95mm_HandSolder
C13, C41, C42, C43, C44, C51, C52, C61, C62: 1uF; C_0603_1608Metric_Pad1.08x0.95mm_HandSolder
C19, C20: 10uF; C_0603_1608Metric_Pad1.08x0.95mm_HandSolder
C31, C32, C33, C34, C35: 470nF; C_0603_1608Metric_Pad1.08x0.95mm_HandSolder
D2, D20: LED; LED_0603_1608Metric_Pad1.05x0.95mm_HandSolder
D3, D6: ESD7104; OnSemi_UDFN-10_1.0x2.5mm_P0.5mm
D7, D8, D9, D10, D11, D12, D13, D14, D15, D16, D17, D19: ESD5B5.0ST1G-N; D_SOD-523
D18: ESD7951S; D_SOD-523
FB1: BLM18KG221SN1D; L_0603_1608Metric_Pad1.05x0.95mm_HandSolder
J1: Conn_01x07_Male; PinHeader_1x07_P2.54mm_Vertical
J2: USB_C_Receptacle; USB_C_Receptacle_XKB_U262-241N-4BV60
J3: Conn_01x08_Male; PinHeader_1x08_P2.54mm_Vertical
J4: USB3_A Receptacle; USB3_A_Receptacle_XKB_U231-091N-4BLRA00-S-1
J5: Conn_01x02_Male; PinHeader_1x02_P2.54mm_Vertical
JP2: SolderJumper_2_Bridged; SolderJumper-2_P1.3mm_Bridged_RoundedPad1.0x1.5mm
L1: 4.7uH; L_1008_2520Metric_Pad1.43x2.20mm_HandSolder; Part Number SPH252012H4R7MT
R1, R2, R6, R7, R8, R19: 0R; R_0603_1608Metric_Pad0.98x0.95mm_HandSolder
R3, R4, R15, R20, R21: 10k; R_0603_1608Metric_Pad0.98x0.95mm_HandSolder
R5: 11.3k; R_0603_1608Metric_Pad0.98x0.95mm_HandSolder; Tolerance 1%
R9, R13, R24: 470R; R_0603_1608Metric_Pad0.98x0.95mm_HandSolder
R22, R23: 0R5; R_0603_1608Metric_Pad0.98x0.95mm_HandSolder
U2: VL670; QFN-48-1EP_6x6mm_P0.4mm_EP4.3x4.3mm
U4: TPS2061C-PXLI; SOT-23-5_HandSoldering
Y1: 25MHz; Crystal_SMD_3225-4Pin_3.2x2.5mm

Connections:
+1V2: C61.1, C62.1, U2.30 (VDD12), U2.46 (LDOVDD12O); also elsewhere on the board
+1V5: C41.1, C42.1, C43.1, C44.1, L1.1, U2.12 (MVDD15), U2.15 (U3TXAVDD15), U2.20 (U3RXAVDD15), U2.47 (LDOVDD15), U2.48 (DCVDD15FB); also elsewhere on the board
+3V3: C31.1, C32.1, C33.1, C34.1, C35.1, R3.1, R4.1, U2.5 (VCC33), U2.9 (LDOVDD33O), U2.27 (VCCU33), U2.35 (VCC33), U2.44 (VCC33); also elsewhere on the board
+5V: C19.1, C51.1, C52.1, D18.1 (A1), J5.1, JP2.2 (B), U2.3 (DCVDD5), U2.10 (LDOVDD5), U4.5 (IN); also elsewhere on the board
+5VP: FB1.2, J2.A4 (VBUS), J2.A9 (VBUS), J2.B4 (VBUS), J2.B9 (VBUS)
+5V_SW: C20.1, D3.1 (TVS1), D3.2 (TVS2), D3.9 (NC2), D3.10 (NC1), D20.2 (A), J4.1 (VBUS), U4.1 (OUT)
/DN_D+: D3.5 (TVS4), D3.6 (NC4), J4.3 (D+), U2.23 (DN_D+)
/DN_D-: D3.4 (TVS3), D3.7 (NC3), J4.2 (D-), U2.24 (DN_D-)
/DN_SSRX+: D6.5 (TVS4), D6.6 (NC4), J4.6 (SSRX+), U2.17 (DN_USB3RX+)
/DN_SSRX-: D6.4 (TVS3), D6.7 (NC3), J4.5 (SSRX-), U2.16 (DN_USB3RX-)
/DN_SSTX+: C8.2, U2.22 (DN_USB3TX+)
/DN_SSTX-: C7.2, U2.21 (DN_USB3TX-)
/DN_TX_AC+: C8.1, D6.2 (TVS2), D6.9 (NC2), J4.8 (SSTX-)
/DN_TX_AC-: C7.1, D6.1 (TVS1), D6.10 (NC1), J4.9 (SSTX+)
/D_DEMUX+: R2.1, U2.26 (UP_D+)
/D_DEMUX-: R1.1, U2.25 (UP_D-)
/SSRX_DEMUX+: U2.19 (UP_USB3RX+); also elsewhere on the board
/SSRX_DEMUX-: U2.18 (UP_USB3RX-); also elsewhere on the board
/SSTX_DEMUX+: U2.13 (UP_USB3TX-); also elsewhere on the board
/SSTX_DEMUX-: U2.14 (UP_USB3TX+); also elsewhere on the board
/USB AC CAP/ESD/MUX/CC1: J2.A5 (CC1); also elsewhere on the board
/USB AC CAP/ESD/MUX/CC2: J2.B5 (CC2); also elsewhere on the board
/USB AC CAP/ESD/MUX/D+: J2.A6 (D+), J2.B6 (D+), R2.2; also elsewhere on the board
/USB AC CAP/ESD/MUX/D-: J2.A7 (D-), J2.B7 (D-), R1.2; also elsewhere on the board
/USB AC CAP/ESD/MUX/RX1+: J2.B11 (RX1+); also elsewhere on the board
/USB AC CAP/ESD/MUX/RX1-: J2.B10 (RX1-); also elsewhere on the board
/USB AC CAP/ESD/MUX/RX2+: J2.A11 (RX2+); also elsewhere on the board
/USB AC CAP/ESD/MUX/RX2-: J2.A10 (RX2-); also elsewhere on the board
/USB AC CAP/ESD/MUX/TX1+: J2.A2 (TX1+); also elsewhere on the board
/USB AC CAP/ESD/MUX/TX1-: J2.A3 (TX1-); also elsewhere on the board
/USB AC CAP/ESD/MUX/TX2+: J2.B2 (TX2+); also elsewhere on the board
/USB AC CAP/ESD/MUX/TX2-: J2.B3 (TX2-); also elsewhere on the board
/eeprom/ISP_MISO: D16.1 (A1), J1.4; also elsewhere on the board
/eeprom/ISP_MOSI: D15.1 (A1), J1.5; also elsewhere on the board
/eeprom/ISP_SCK: D14.1 (A1), J1.2; also elsewhere on the board
/eeprom/MISO: U2.43 (SPI_MISO); also elsewhere on the board
/eeprom/MOSI: U2.42 (SPI_MOSI); also elsewhere on the board
/eeprom/SCK: U2.40 (SPI_SCLK); also elsewhere on the board
/eeprom/~CS: U2.41 (~SPI_SS); also elsewhere on the board
/eeprom/~ISP_CS: D13.1 (A1), J1.3; also elsewhere on the board
GND: C10.2, C11.2, C13.2, C31.2, C32.2, C33.2, C34.2, C35.2, C41.2, C42.2, C43.2, C44.2, C51.2, C52.2, C61.2, C62.2, D2.1 (K), D3.3 (COM), D3.8 (GND), D6.3 (COM), D6.8 (GND), D7.2 (A2), D8.2 (A2), D9.2 (A2), D10.2 (A2), D11.2 (A2), D12.2 (A2), D13.2 (A2), D14.2 (A2), D15.2 (A2), D16.2 (A2), D17.2 (A2), D18.2 (A2), D19.2 (A2), J1.1, J1.7, J2.A1 (GND), J2.A12 (GND), J2.B1 (GND), J2.B12 (GND), J2.S1 (SHIELD), J3.8, J4.4 (GND), J4.7 (DRAIN), J4.10 (SHIELD), J5.2, R5.2, R6.2, R7.2, R8.2, R15.2, R19.2, R20.2, R21.2, R22.2, R23.2, R24.2, U2.1 (DCGND), U2.49 (GND), U4.2 (GND), Y1.2, Y1.4; also elsewhere on the board
unnamed: C10.1, U2.29 (XI), Y1.3
unnamed: C11.1, U2.28 (XO), Y1.1
unnamed: C19.2, R22.1
unnamed: C20.2, R23.1
unnamed: D2.2 (A), R9.1, R13.1
unnamed: D7.1 (A1), J3.2, R9.2, U2.36 (GPIO1_1/GPIO_TP2)
unnamed: D8.1 (A1), J3.3, R21.1, U2.39 (GPIO1_0/GPIO_TP1)
unnamed: D9.1 (A1), J3.4, R20.1, U2.38 (GPIO1_2/GPIO_TP3)
unnamed: D10.1 (A1), J3.5, U2.7 (GPIO2_0/UART_RX)
unnamed: D11.1 (A1), J3.6, U2.6 (GPIO2_1/UART_TX)
unnamed: D12.1 (A1), J3.7, U2.45 (GPIO3_1/GPIO_TP4)
unnamed: D19.1 (A1), J3.1, R13.2, U2.4 (GPIO3_0/STATUS)
unnamed: D20.1 (K), R24.1
unnamed: FB1.1, JP2.1 (A)
unnamed: L1.2, U2.2 (LX)
unnamed: R5.1, U2.11 (REXT)
unnamed: R6.1, U2.33 (STRP0)
unnamed: R7.1, U2.32 (STRP1)
unnamed: R8.1, U2.31 (STRP2)
unnamed: R15.1, U2.37 (GPIO1_3/DN_PWREN), U4.4 (~EN)
unnamed: R19.1, U2.8 (TESTEN)
~EXT_RESET: C13.1, D17.1 (A1), J1.6, R3.2, R4.2, U2.34 (~RESET~); also elsewhere on the board

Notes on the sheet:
Note 1:
Note 4:
Pure USB3 by default. USB2 transactions are translated to USB3. Install D+/D- jumpers only when USB2 direct pass- through is needed.
Note 3:
EEPROM
Note 5:
By default, both VL670 and ISP header are connected, to allow probing SPI while VL670 is running. To program the EEPROM, a programmer must pull ~ISP_ENABLE~ low from the ISP header (bridge pin 6 "~EN~"& 7 "GND" on J1), to avoid bus contention.
C44 MUST be close to L1
close to VL670, one per pin
On VL670, without R20, firewire reads false input and random reset.
Note 6:
Internal 3.3 V, 1.5 V, 1.2 V supplies should only power VL670 & EEPROM and the SPI multiplexers. DON'T CONNECT TO OTHER CHIPS.
VL670: 11.3k VL671: 11.8k
Note 2:
Cut JP2 to isolate USB connector from global 5 V rail for debugging with external power.
R51, R52 damp FB1 inductance resonance. Without FB1, use 0R.
PCB layout-specific components
FB1 may resonate, see capacitor C19, C20
Note:
C1+C5+C7=73 nF
VL671: 1.2V
VL670: R9 VL671: R13

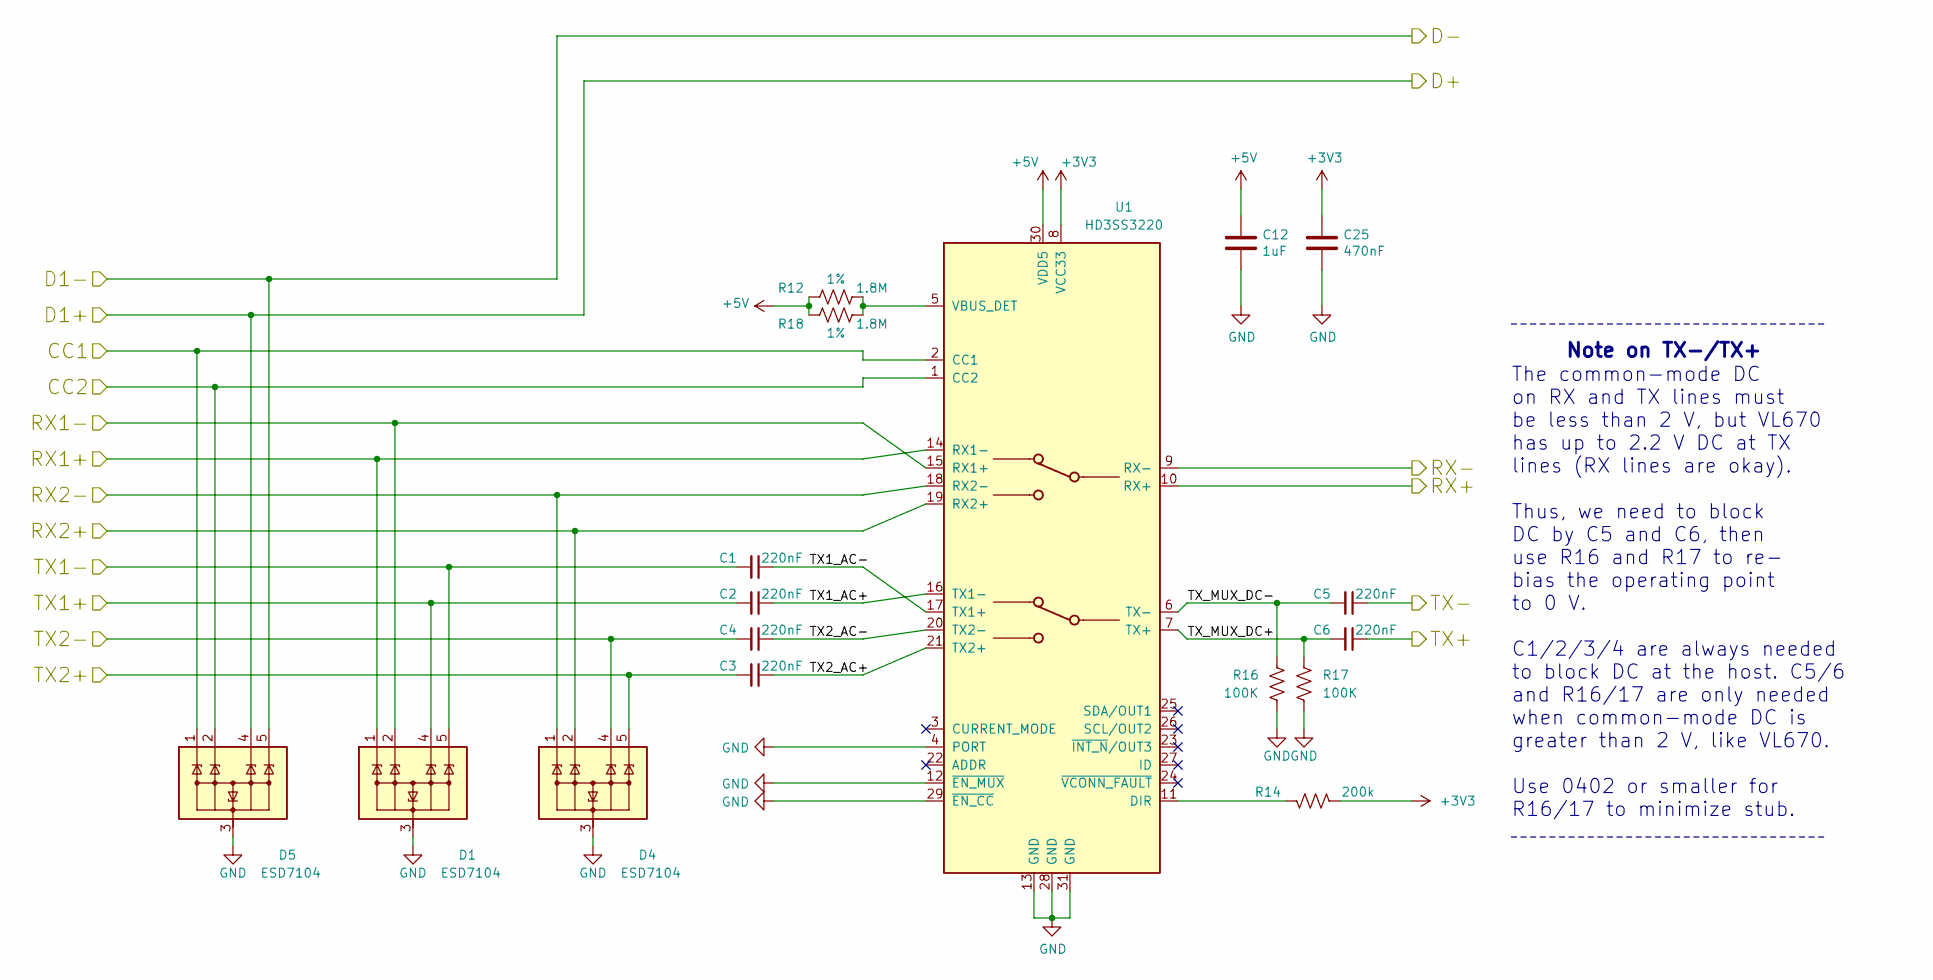
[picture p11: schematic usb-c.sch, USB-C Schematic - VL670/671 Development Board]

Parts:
C1, C2, C3, C4, C5, C6: 220nF; C_0603_1608Metric_Pad1.08x0.95mm_HandSolder
C12: 1uF; C_0603_1608Metric_Pad1.08x0.95mm_HandSolder
C25: 470nF; C_0603_1608Metric_Pad1.08x0.95mm_HandSolder
D1, D4, D5: ESD7104; OnSemi_UDFN-10_1.0x2.5mm_P0.5mm
R12, R18: 1.8M; R_0603_1608Metric_Pad0.98x0.95mm_HandSolder; Tolerance 1%
R14: 200k; R_0603_1608Metric_Pad0.98x0.95mm_HandSolder
R16, R17: 100K; R_0402_1005Metric_Pad0.72x0.64mm_HandSolder
U1: HD3SS3220; Texas_VQFN-RNH-30

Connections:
+3V3: C25.1, R14.2, U1.8 (VCC33); also elsewhere on the board
+5V: C12.1, R12.2, R18.2, U1.30 (VDD5); also elsewhere on the board
/SSRX_DEMUX+: U1.10 (RX+); also elsewhere on the board
/SSRX_DEMUX-: U1.9 (RX-); also elsewhere on the board
/SSTX_DEMUX+: C6.1; also elsewhere on the board
/SSTX_DEMUX-: C5.1; also elsewhere on the board
/USB AC CAP/ESD/MUX/CC1: D5.1 (TVS1), D5.10 (NC1), U1.2 (CC1); also elsewhere on the board
/USB AC CAP/ESD/MUX/CC2: D5.2 (TVS2), D5.9 (NC2), U1.1 (CC2); also elsewhere on the board
/USB AC CAP/ESD/MUX/D+: D5.4 (TVS3), D5.7 (NC3); also elsewhere on the board
/USB AC CAP/ESD/MUX/D-: D5.5 (TVS4), D5.6 (NC4); also elsewhere on the board
/USB AC CAP/ESD/MUX/RX1+: D1.1 (TVS1), D1.10 (NC1), U1.14 (RX1-); also elsewhere on the board
/USB AC CAP/ESD/MUX/RX1-: D1.2 (TVS2), D1.9 (NC2), U1.15 (RX1+); also elsewhere on the board
/USB AC CAP/ESD/MUX/RX2+: D4.2 (TVS2), D4.9 (NC2), U1.19 (RX2+); also elsewhere on the board
/USB AC CAP/ESD/MUX/RX2-: D4.1 (TVS1), D4.10 (NC1), U1.18 (RX2-); also elsewhere on the board
/USB AC CAP/ESD/MUX/TX1+: C2.2, D1.4 (TVS3), D1.7 (NC3); also elsewhere on the board
/USB AC CAP/ESD/MUX/TX1-: C1.2, D1.5 (TVS4), D1.6 (NC4); also elsewhere on the board
/USB AC CAP/ESD/MUX/TX1_AC+: C2.1, U1.16 (TX1-)
/USB AC CAP/ESD/MUX/TX1_AC-: C1.1, U1.17 (TX1+)
/USB AC CAP/ESD/MUX/TX2+: C3.2, D4.5 (TVS4), D4.6 (NC4); also elsewhere on the board
/USB AC CAP/ESD/MUX/TX2-: C4.2, D4.4 (TVS3), D4.7 (NC3); also elsewhere on the board
/USB AC CAP/ESD/MUX/TX2_AC+: C3.1, U1.21 (TX2+)
/USB AC CAP/ESD/MUX/TX2_AC-: C4.1, U1.20 (TX2-)
/USB AC CAP/ESD/MUX/TX_MUX_DC+: C6.2, R17.1, U1.7 (TX+)
/USB AC CAP/ESD/MUX/TX_MUX_DC-: C5.2, R16.1, U1.6 (TX-)
GND: C12.2, C25.2, D1.3 (COM), D1.8 (GND), D4.3 (COM), D4.8 (GND), D5.3 (COM), D5.8 (GND), R16.2, R17.2, U1.4 (PORT), U1.12 (~EN_MUX), U1.13 (GND), U1.28 (GND), U1.29 (~EN_CC), U1.31 (GND); also elsewhere on the board
unnamed: R12.1, R18.1, U1.5 (VBUS_DET)
unnamed: R14.1, U1.11 (DIR)

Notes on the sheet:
The common-mode DC on RX and TX lines must be less than 2 V, but VL670 has up to 2.2 V DC at TX lines (RX lines are okay). Thus, we need to block DC by C5 and C6, then use R16 and R17 to re- bias the operating point to 0 V. C1/2/3/4 are always needed to block DC at the host. C5/6 and R16/17 are onl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
Note on TX-/TX+

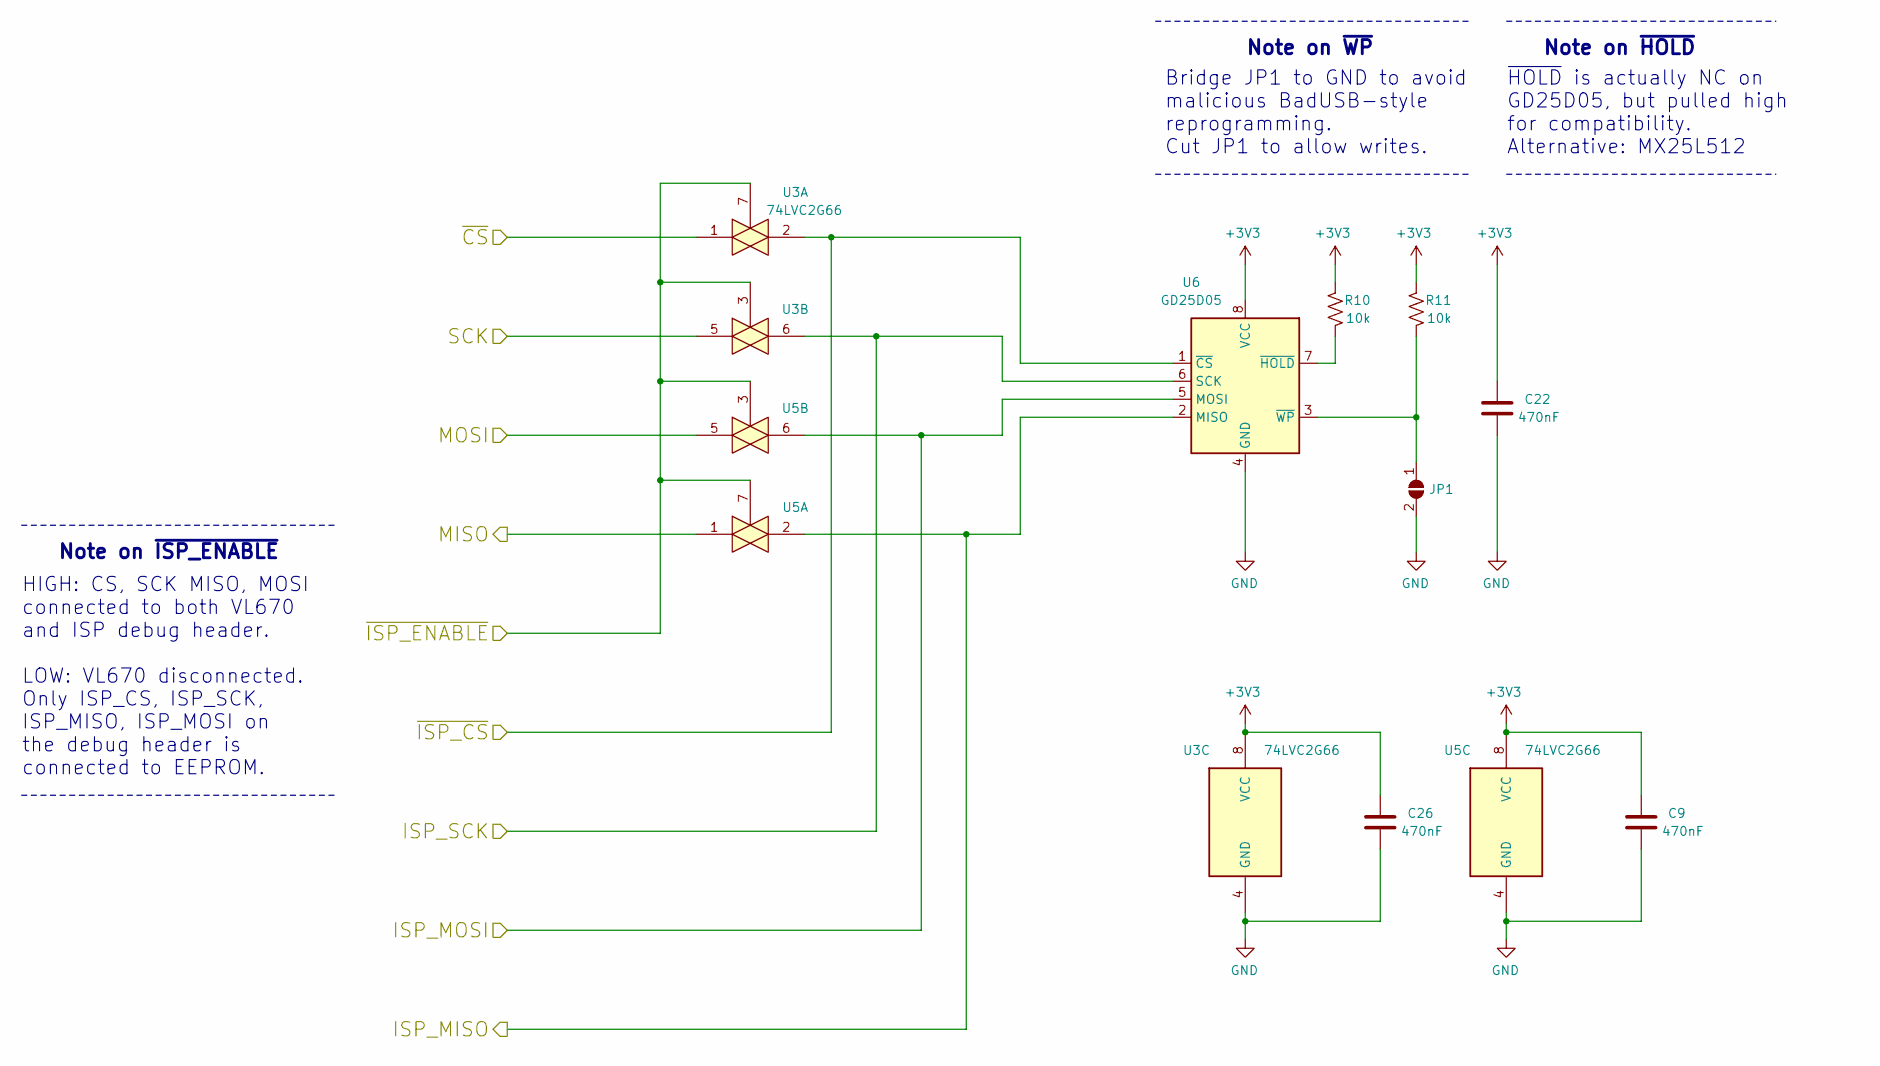
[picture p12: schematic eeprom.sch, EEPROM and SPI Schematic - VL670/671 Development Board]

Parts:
C9, C22, C26: 470nF; C_0603_1608Metric_Pad1.08x0.95mm_HandSolder
JP1: SolderJumper_2_Open; SolderJumper-2_P1.3mm_Open_RoundedPad1.0x1.5mm
R10, R11: 10k; R_0603_1608Metric_Pad0.98x0.95mm_HandSolder
U3, U5: 74LVC2G66; VSSOP-8_2.4x2.1mm_P0.5mm
U6: GD25D05; SOIC-8_3.9x4.9mm_P1.27mm

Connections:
+3V3: C9.1, C22.1, C26.1, R10.1, R11.1, U3.8 (VCC), U5.8 (VCC), U6.8 (VCC); also elsewhere on the board
/eeprom/ISP_MISO: U5.2, U6.2 (MISO); also elsewhere on the board
/eeprom/ISP_MOSI: U5.6, U6.5 (MOSI); also elsewhere on the board
/eeprom/ISP_SCK: U3.6, U6.6 (SCK); also elsewhere on the board
/eeprom/MISO: U5.1; also elsewhere on the board
/eeprom/MOSI: U5.5; also elsewhere on the board
/eeprom/SCK: U3.5; also elsewhere on the board
/eeprom/~CS: U3.1; also elsewhere on the board
/eeprom/~ISP_CS: U3.2, U6.1 (~CS); also elsewhere on the board
GND: C9.2, C22.2, C26.2, JP1.2 (B), U3.4 (GND), U5.4 (GND), U6.4 (GND); also elsewhere on the board
unnamed: JP1.1 (A), R11.2, U6.3 (~WP)
unnamed: R10.2, U6.7 (~HOLD)
~EXT_RESET: U3.3, U3.7, U5.3, U5.7; also elsewhere on the board

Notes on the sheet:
HIGH: CS, SCK MISO, MOSI connected to both VL670 and ISP debug header. LOW: VL670 disconnected. Only ISP_CS, ISP_SCK, ISP_MISO, ISP_MOSI on the debug header is connected to EEPROM.
Note on ~ISP_ENABLE
Bridge JP1 to GND to avoid malicious BadUSB-style reprogramming. Cut JP1 to allow writes.
Note on ~WP
Note on ~HOLD
~HOLD~ is actually NC on GD25D05, but pulled high for compatibility. Alternative: MX25L512

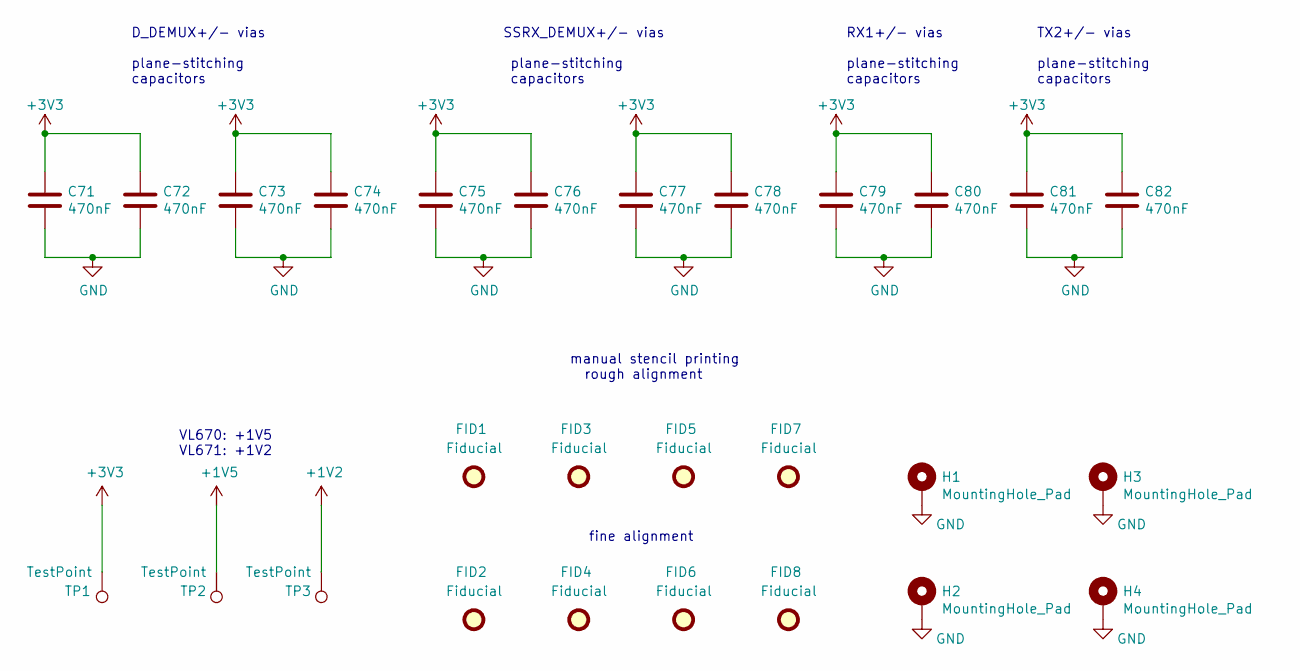
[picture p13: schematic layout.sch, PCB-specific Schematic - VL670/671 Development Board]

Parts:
C71, C72, C73, C74, C75, C76, C77, C78, C79, C80, C81, C82: 470nF; C_0402_1005Metric_Pad0.74x0.62mm_HandSolder
FID1, FID3, FID5, FID7: Fiducial; StencilFiducial_1mm
FID2, FID4, FID6, FID8: Fiducial; StencilFiducial_0.5mm
H1, H2, H3, H4: MountingHole_Pad; MountingHole_2.5mm_Pad_Via
TP1, TP2, TP3: TestPoint; TestPoint_Pad_D1.0mm

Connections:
+1V2: TP3.1; also elsewhere on the board
+1V5: TP2.1; also elsewhere on the board
+3V3: C71.1, C72.1, C73.1, C74.1, C75.1, C76.1, C77.1, C78.1, C79.1, C80.1, C81.1, C82.1, TP1.1; also elsewhere on the board
GND: C71.2, C72.2, C73.2, C74.2, C75.2, C76.2, C77.2, C78.2, C79.2, C80.2, C81.2, C82.2, H1.1, H2.1, H3.1, H4.1; also elsewhere on the board

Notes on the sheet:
D_DEMUX+/- vias plane-stitching capacitors
RX1+/- vias plane-stitching capacitors
SSRX_DEMUX+/- vias plane-stitching capacitors
TX2+/- vias plane-stitching capacitors
fine alignment
manual stencil printing rough alignment
VL670: +1V5 VL671: +1V2

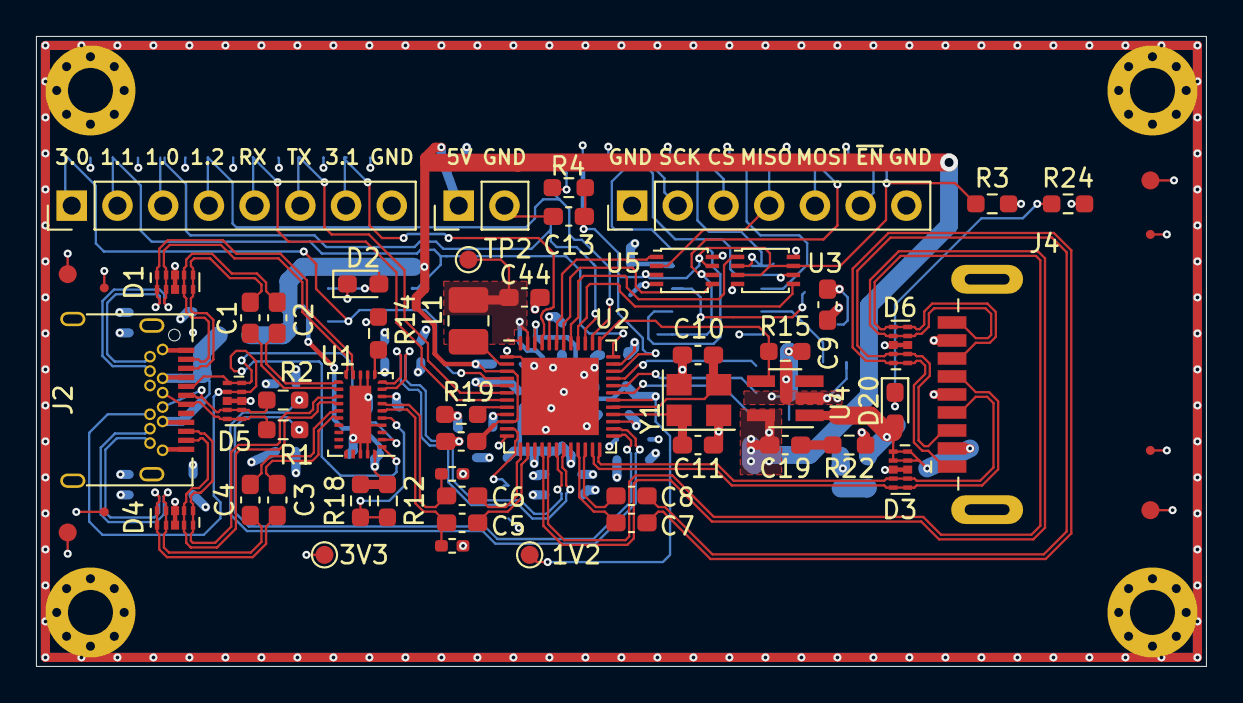
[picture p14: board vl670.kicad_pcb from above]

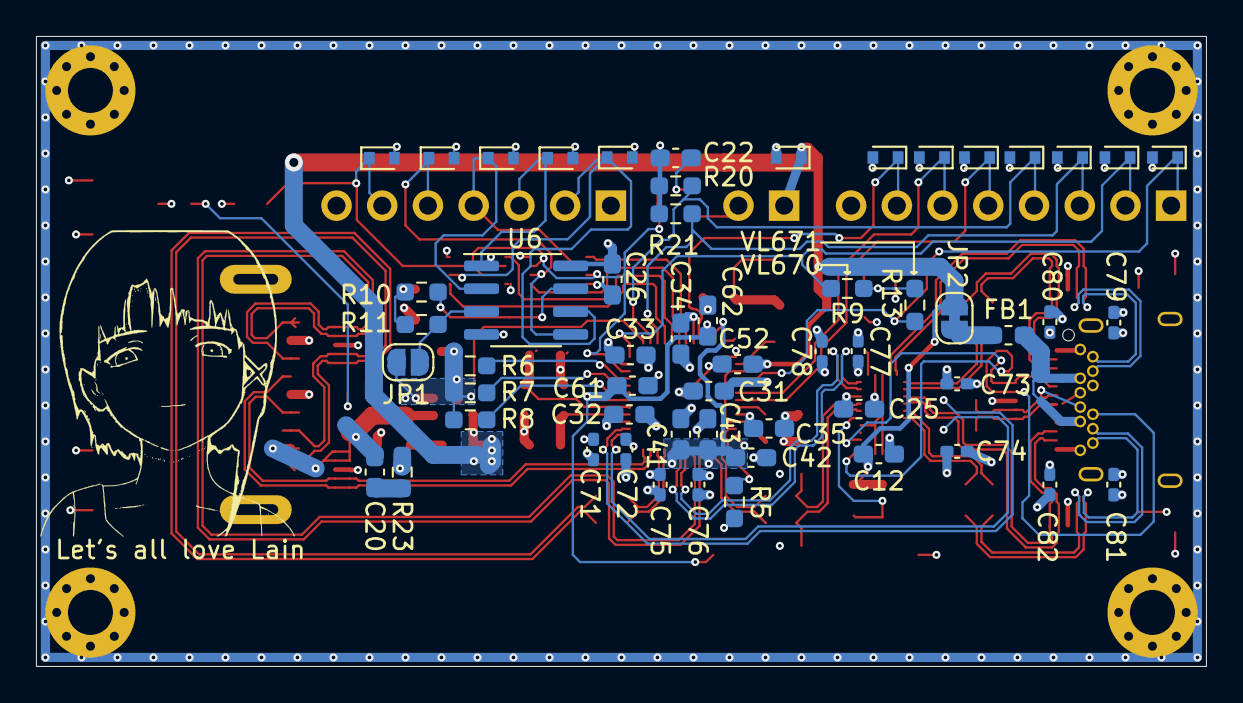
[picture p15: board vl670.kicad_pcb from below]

Board: 4 copper layers, 65.0 x 35.0 mm, 118 parts (56 on the bottom side), 73 nets.

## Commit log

2021-04-09 initial commit.
    [eeprom.sch, prog.sch, usb-c.sch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]
2021-06-18 First private release.
    [eeprom.sch, layout.sch, usb-c.sch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]
2021-06-18 Change R13 to a no-connection item
    [layout.sch, usb-c.sch, vl670.kicad_pcb]
2021-06-18 Change GPIO connections to match firmware.
    [vl670.kicad_pcb, vl670.sch]
2021-06-29 various changes for v0.01 public release.
    [eeprom.sch, layout.sch, usb-c.sch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]
2021-06-29 gerber: add gerber files.
    [vl670-B_Cu.gbr, vl670-B_Mask.gbr, vl670-B_Paste.gbr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]
2021-06-29 README.md: describe PCB stack-up.
2021-06-29 vl670-schematics.pdf: add PDF schematics.
2021-06-29 rename components and footprints.
    [vl670.kicad_pcb, vl670.sch]
2021-06-30 README.md: add schematics links
2021-06-30 README.md: change schematic links to "raw"
2021-07-01 vl670-schematics.pdf: use machine-readable PDF, not raster.
2021-07-02 README.md: more information on voltage level and debug headers.
2021-07-04 README.md: power and signal integrity.
2021-07-04 README.md: adjust power integrity description.
2021-07-06 README.md: quartz crystal loading capacitance bug.
2021-07-09 bom/README.md: add BOM draft.
2021-07-09 README.md: add BOM link.
2021-07-10 bom/README.md: fix incorrect capacitor numbers.
2021-07-26 README.md: update on inrush current.
2021-08-12 vl670.sch: change crystal and loading capacitance
    [vl670.sch]
2021-08-12 bom/README.md: update BOM for XTAL and capacitors.
2021-08-12 README.md: 5 V inrush problem solved.
2021-08-12 vl670.sch: change downstream capacitance value to 220 uF.
    [vl670.sch]
2021-08-12 bom/README.md: remove 100 uF, more 220 uF
2021-08-12 schematics/vl670-schematics.pdf: regenerate schematics.
2021-10-26 schematics: update schematics and layouts.
2021-10-26 gerber: update gerber
    [vl670-B_Cu.gbr, vl670-B_Mask.gbr, vl670-B_Paste.gbr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]
2021-10-26 bom: update BOM
2021-10-27 fp-info-cache: needed for fresh KiCad installs.
2021-10-27 vl670-cache.lib: needed for fresh KiCad installs.
2021-10-31 vl670.kicad_pcb: adjust copper fills
    [vl670.kicad_pcb]
2021-10-31 gerber: update gerber files
    [vl670-B_Cu.gbr, vl670-B_Mask.gbr, vl670-B_Paste.gbr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]
